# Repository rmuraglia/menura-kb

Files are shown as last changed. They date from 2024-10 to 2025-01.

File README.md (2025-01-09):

# menura

menura-build-collage

The menura is a 30 to 36 key wireless split MX keyboard compatible with the [VIK standard](https://github.com/sadekbaroudi/vik) for modular peripheral device support.

The core concept is a single PCB design which supports *mimicry* of many physical layouts, allowing for non-committal experimentation.
This is accomplished by utilization of overlapping (but not mutually exclusive) switch footprints, and a PCB shape which permits effective conversion to the unibody form factor.

The menura is named for the [lyrebird](https://en.wikipedia.org/wiki/Lyrebird) (scientific name, *menura*), due to its skill in mimicry:

> They are most notable for their impressive ability to mimic natural and artificial sounds from their environment  
> [...]  
> It is one of the world's largest songbirds, and is renowned for its elaborate tail and courtship displays, and its excellent mimicry.

# Design goals

The primary design goal was to create a PCB that would allow you to seamlessly switch between and try out many layouts, gradually reducing your keycount from a 3x5+3 layout like on the [5 column ffkb](https://fingerpunch.xyz/product-tag/ffkb/), to 3x5+2 like the [sweep](https://github.com/davidphilipbarr/Sweep), then eventually a 23332+2 like the [hummingbird](https://github.com/PJE66/hummingbird).  
In parallel to the keycount flexibility, I also wanted it to be easy to try out both a true split layout as well as unibody layouts ranging from the aggressively angled like the [barobord](https://github.com/sadekbaroudi/barobord) to more relaxed angles like the [duet](https://github.com/zzeneg/duet).

To accomplish this goal, the menura has two key features:

## Partially overlapping switch footprints

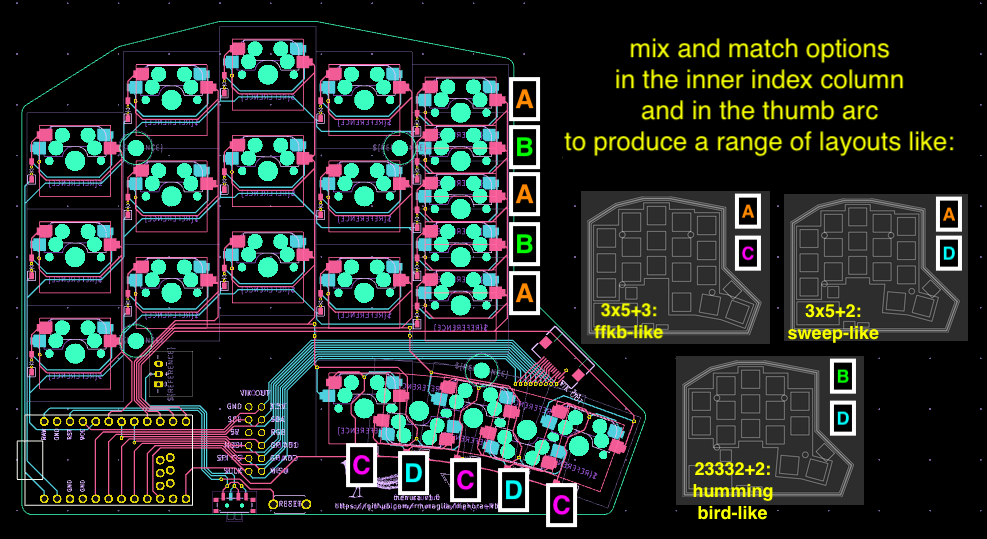
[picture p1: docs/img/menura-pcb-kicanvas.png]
menura-pcb-kicanvas


By carefully arranging switch footprints, we can set it up such that *all* hotswap sockets can be soldered without interfering with each other.  
This allows you to defer the choice of layout to case assembly time rather than being forced to commit irreversibly at PCB build time, encouraging experimentation.

This requires a concession to use MX switches only.
Reduced choc spacing and the shape of choc hotswap sockets make simultaneous installation of all switch sockets impossible (at least without compromising on switch rotation, which impacts keycap compatibility, etc).

## MCU relocation and unibody wedges

To allow for effective and flexible unibody conversion, the MCUs needed to be relocated out of their conventional spot next to the inner index column.
Without this modification, we cannot get the halves close enough together to accurately mimic unibody layouts.

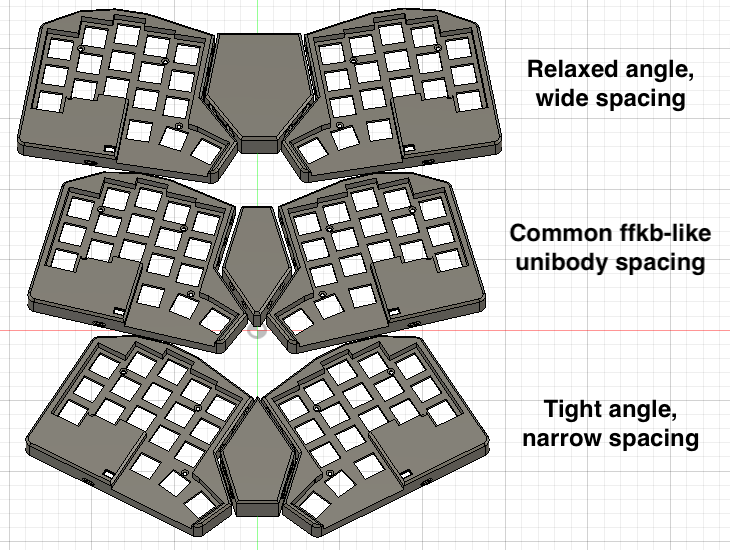
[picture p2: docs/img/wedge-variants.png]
wedge-variants


The resulting PCB edge cut enables a case + wedge design that can reproduce a wide range of unibody angles and inter-half distances.  
The case designs in this repo support insertion of magnets into the case walls to allow for simple insertion and removal of the wedges.

## VIK support

Finally, after accomplishing the two previous goals, to lean into the theme of flexibility, versatility and experimentation, we added support for the [VIK standard](https://github.com/sadekbaroudi/vik) for peripheral device support.
This means that with one flat flexible cable (FFC), you can integrate a wide range of add ons, like a nice!view display or a cirque trackpad.

# Building your own menura

To build your own menura:

1. Order PCBs from somewhere like [JLC](https://jlcpcb.com/) using the gerbers in the [releases](https://github.com/rmuraglia/menura-kb/releases) section of this repo
2. Follow the [build guide](/docs/build-guide.md) to:
    1. Solder the PCB
    2. Assemble the case, using a case printed from the [`case/`](/case/) directory
3. Flash the [ZMK studio](https://zmk.dev/docs/features/studio) ready firmware from the [releases](https://github.com/rmuraglia/menura-kb/releases) section of this repo for testing and basic keymap customization
4. If needed (for advanced keymap configuration), write and flash your own ZMK firmware, using the [menura shield module](https://github.com/rmuraglia/zmk-keyboards-menura). The ZMK docs has a page on [modules](https://zmk.dev/docs/features/modules), for more details on using modules

If you want to quickly inspect the PCB or schematic to debug something or further understand the design, you can quickly view these in browser with kicanvas: [menura in kicanvas](https://kicanvas.org/?github=https://github.com/rmuraglia/menura-kb/blob/main/pcb/menura.kicad_pro).  
Tip: in the pcb view, within the sidebar's objects section (with the triangle, circle and square icon), you can turn the slider for "zones" all the way down to stop displaying the ground fill to better see the traces and footprints. 

# Inspiration and references

The board's concept, with flexible key positions and the ability to use two split halves as one whole was inspired heavily by [ErgoTravelXT](https://github.com/FIXMBR/ErgoTravelXT).  
The layouts the menura attempts to mimic include the [ffkb](https://fingerpunch.xyz/product-tag/ffkb/), the [vulpes minora](https://github.com/sadekbaroudi/vulpes-minora), the [sweep](https://github.com/davidphilipbarr/Sweep) and [urchin](https://github.com/duckyb/urchin), the [hummingbird](https://github.com/PJE66/hummingbird), and countless others.

On the design side, I learned a ton on the ergogen side from the [nostrum](https://github.com/bennytrouser/nostrum), [trochilidae](https://github.com/jcmkk3/trochilidae) (rufous and berylline), and [corax](https://github.com/dnlbauer/corax-keyboard) configs, as well as [flatfootfox's guide](https://flatfootfox.com/ergogen-introduction/).  
Other boards I studied on the kicad side include the vulpes minora, urchin, [temper](https://github.com/raeedcho/temper) and [klotz](https://github.com/GEIGEIGEIST/KLOTZ).
zzeneg's [zzkeeb](https://github.com/zzeneg/zzkeeb) library was critical in helping me cut through the endless options for kicad footprints to find an organized and curated set to start with.

# Thanks

I'd like to thank Sadek Baroudi and the members of the [fingerpunch discord](https://discord.gg/ewS6xbCgPb) community, especially Hazel who (unwillingly) taught me everything I know, Saixos and bravekarma for teaching me how to do things right (even if I usually ignored their suggestions), and reeve, damselfly, Yingeling and PyntieHet for celebrating every small step along the way and encouraging me to finish the project.

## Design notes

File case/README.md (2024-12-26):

I've tried to make design files available in a wide variety of formats to support editing and redesign as needed:

1. `fusion/` contains fusion 360 files for complete control over the timeline and features for editing
2. `step/` contains step files for non-meshified exports which better preserve the underlying geometry for minor tweaks and portability outside of fusion
3. `stl/` contains exported meshes, which are not great for editing, but are convenient for printing
4. `dxf/` contains outlines which you can use to start a new case design from scratch. See [the case design docs](/docs/case-design.md#shadow-line) for some notes on the generated outlines (and why you may want to export something different from ergogen, depending on your use case)

The exported case files are generally going to follow one of the three naming schemes:

- `bottom`: this is the simplest case -- there's just one common bottom for all cases, so there's no variants to track. Fusion and step files will have one common file for both halves, whereas stl will export a left and right separately.
- `top_${layout}`: where layout is be one of `3x5_3`, `3x5_2`, `23332_2` etc. For stls, there's again left and right exports, as well as exports for variants with `no-rst`, no cutout for the reset button
- `wedge_${angle}_${distance}_${feature}`: the angle refers to the angle between a keyboard half and the vertical, and the distance refers to the distance between the top corners of the keyboard halves. The (optional) feature represents any peripheral you may mount in the wedge, like a cirque trackpad.

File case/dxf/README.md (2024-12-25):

- the `raw` directory contains dxf exports from ergogen as is
- the `cleaned` directory contains dxf exports from fusion after I've done some minor clean up and modification (closing gaps in outlines, trimming internal lines, extending lines to section off areas that I want to treat as different faces)
- the `components` directory contains dxfs for components (e.g. cirque trackpad) or other reusable portions (e.g. magnet cutouts) from the designs
    - the `cirque` dxf is derived from the [bad wings v1 step case file](https://github.com/hazels-garage/bad-wings/tree/master/v1/cases/original)
    - the magnets are named as `magnet-${diameter}-${edge}`, where the edge is either the shorter or longer edge of the case where the magnets will be embedded

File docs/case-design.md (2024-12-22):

This is more of a personal archival note to document how I did this case design, and isn't really intended for external consumption, but you're welcome to browse it.

# General case shape

Overall, my starting point for building understanding on fusion 360 and case design were:

- [Sadek Baroudi's case design guide](https://github.com/sadekbaroudi/keyboard-guides/tree/master/cases)
- [Hazel's bad wings v1 original case](https://github.com/hazels-garage/bad-wings/tree/master/v1/cases/original), and the minor tinkering I did in that case
- The (unpublished, but shared privately) fusion design file for the [vulpes minora case](https://github.com/sadekbaroudi/vulpes-minora/tree/master/case).

My general approach was going to follow the same general case design composed of:

- a flat bottom plate
- a top switch plate, with offset walls to "reach down" to the plate, and hollowed out areas to provide clearance for top-of-pcb components like the MCU

## Measurements

Base measurements:

- PCB and plate thickness: 1.6mm
- hotswap socket thickness: 1.8mm
- switch bottom to housing to top of clip point: 5mm (from [cherry switch diagram](https://www.cherry.de/en-gb/gaming/developer))
- PCB bottom to USB top: 10mm (on left side, where USB is taller -- this is the tallest component which will determine the overall height)

cherry-switch-dimensions

In general, this integrated plate design suggests that using the bottom of the switch plate as the vertical "origin" from which we will determine relative measurements makes sense.

Derived measurements:

- switch plate top to usb top: 3.4 (10 - 1.6 - 5)
- switch plate bottom to usb top: 5 (3.4 + 1.6)
- mcu hollowed out area: 5.4 (5 + 0.4 buffer) to 7 (+1.6 wall thickness)
    - important: +7 is the max height
    - note that the 0.4 buffer sounds small, but really the height of the usb port (with magnetic tip) is much more than the mcu board itself, so this should be plenty
- switch plate top to bottom of sockets: 6.8 (5 - 1.6 (housing minus plate thickness) + 1.6 (pcb) + 1.8 (sockets))
    - note: Sadek's case guide suggests 8 mm as a safe height for MX hotswap

## Shadow line

This [hackaday article](https://hackaday.com/2023/08/07/enhance-your-enclosures-with-a-shadow-line/) gives a good overview of shadow lines, but the concept is that you use mating pieces, such that on the inside, the parts are flush, but on the outside there is a small gap -- this gap, backed by the flush pieces gives a better appearance of uniformity at the seam, compared to just attempting to get the outermost walls flush with each other.

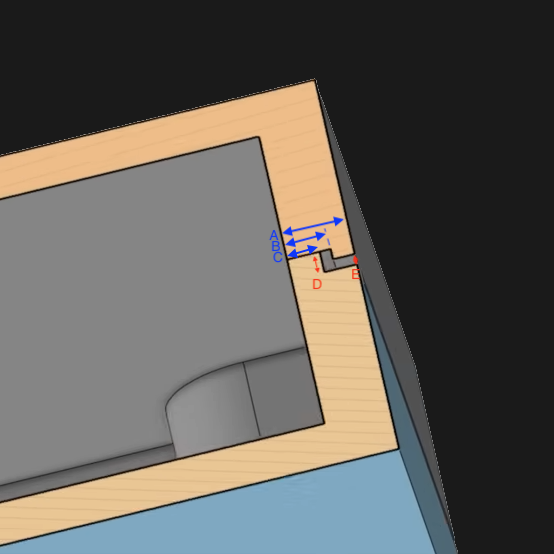
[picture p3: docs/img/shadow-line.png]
shadow-line


I rotated and annotated it, to suit my desire to have the top create the gap with an overhang, rather than the bottom reaching up.  
For ease of FDM printing, I was advised to choose measurements in multiples of the nozzle and layer height, so 0.4mm was selected. Some discussion in discord on the topic: [link](https://discord.com/channels/989552667330228374/1104037399517986947/1306638628612739103).

The measurements I ended up choosing were as follows:

- total wall thickness (A): 3mm
- inner wall thickness (C): 1.2mm
- horizontal gap: 0.6 (3 - 1.2 - 1.2 for even wall thicknesses)
    - implies B (outer wall offset) is 1.8 (1.2 + 0.6)
- vertical gap (E): 0.4
- vertical mating notch (D): 1.2 (0.4 gap + 0.8 step)

To minimize repeated manual work in fusion (offsetting curves in sketches), I added outlines for these additional wall thicknesses to my ergogen config (see `(board|shadow)_(inner|outer)_wall`).  
These outlines are all generated with no fillet, to help fusion import gapless DXFs that require minimal fixing.  
Note that this lack of filleting in the ergogen stage will come back to bite us in the [cosmetics](#cosmetics) section, so be sure to check that out.

# Fusion

With all of those measurements in place, we can do the basic extrudes in fusion that give the case its general shape:

## Sketch modifications

Before extruding, I did do some minor sketch modifications to make the extruding easier:

1. I sectioned off the hollow areas, so it can be treated as a different face for extrusion. This generally means extending some lines:
    1. bottom pinky bottom edge to the left wall
    2. tucky thumb tucky edge to bottom wall
    3. reachy thumb reachy edge to bottom wall
    4. vik top and bottom edges to right wall
2. I also cleaned up some leftover, internal lines that did not meaningfully contribute to the outline:
    1. bottom of power switch
    2. bottom left mounting hole
    3. vik and jst overlap
3. Last to provide a wall to connect the raised, hollow areas with switchplate-height part of the case, I added some offsets around the mcu and vik connector.

## Extrudes

1. Bottom going up:
    1. main pcb area: 1.6 baseline thickness
    2. inner ring: 1.6 base + 0.4 gap + 0.8 step = 2.8
    3. middle and outer ring: 1.6 baseline thickness
2. Top going down (from switch plate bottom):
    1. inner + middle wall: 6.8 (meet the 1.2 extra height of the inner ring from the bottom to make a flush 8mm height)
    2. outer ring: 7.6 (6.8 + 0.8 step, leave a 0.4mm shadow line gap)
3. Top going up (from switch plate bottom):
    1. switch plate and thumb cutout: 1.6 baseline thickness
    2. solid max height area (e.g. connecting walls to hollow areas, areas between switches and outer edge of case): 7mm (previously determined max height)
    2. mcu hollowed out area: 5.4 - 7

At this point, I also add the m2 countersunk holes at all the mounting points. 
Note that the outer diameter of the countersunk screw head clearance is 4.4mm.

## Component cutouts

Next we need to add cutouts or windows for all the components.
Luckily, the ergogen config already has these rendered in the sketch, so all we have to do is *project* a relevant line from that sketch onto the desired plane, then draw around that as a reference.

### USB port

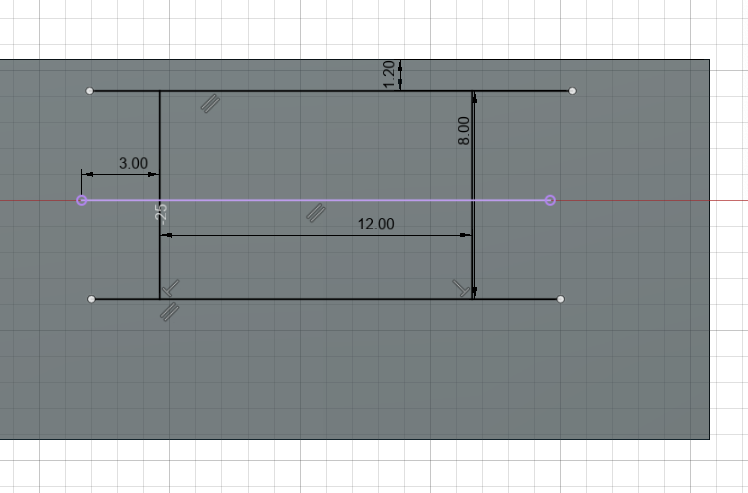
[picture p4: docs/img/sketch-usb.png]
sketch-usb


1. Project a line from the MCU outline to know where the cutout should be centered
2. We know that the top of the USB port *should* be 1.6 to 2 mm from the top of the case (based on the case thickness + 0.4 buffer we allowed)
3. So we start the cutout at **1.2mm from the top** of the case to give a bit more breathing room
4. Then we know we want the cutout to be **8mm tall**, just from other designs -- this gives room for the chunky magnetic tip, and gives some vertical allowance for the flipped MCU on the right/left sides which influences the USB port mounting
5. Then we see the projected line is *18mm* long, and we want our cutout to be centered along that. We want the cutout to be **12mm wide** (again from other designs), so we start the cutout **3mm offset from the end** of the projected line

### Power switch

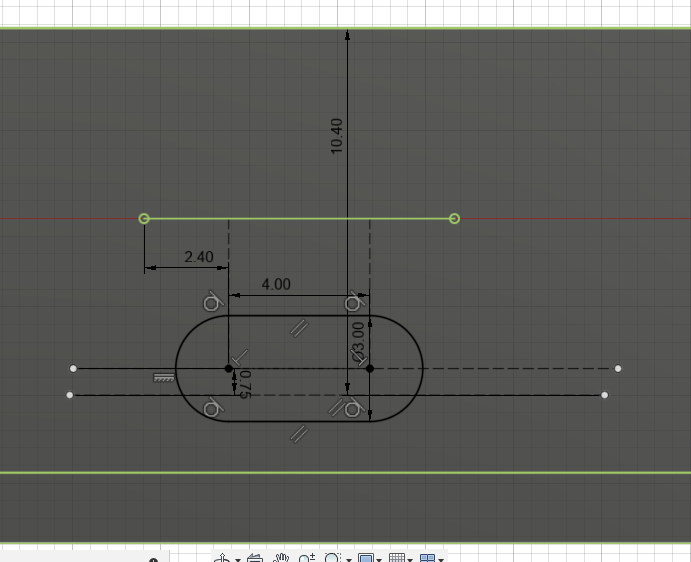
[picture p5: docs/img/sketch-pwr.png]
sketch-pwr


1. The power switch sits on top of the PCB, so we first make a reference line 10.4mm from the top of the case for the top of the PCB: 7 from top of case to switchplate bottom + 5 for switchplate top to pcb top - 1.6 for switchplate thickness
2. The projected line is 8.8mm wide, and we want our power switch cutout slot to be constructed as a center-to-center slot, with a 4mm wide distance between centers, so we measure a horizontal offset of 2.4mm
3. The slot is vertically centered 0.75mm above the top of the PCB (I honestly don't remember why, this is probably the half the thickness of the power switch)
4. Finally, we create the slot based on those centers, with a slot height of 3mm, giving us two 1.5mm radius semi circles on the ends.

For the power switch, we additionally create a second cutout in the wall to create a channel for the protruding switch to go through during PCB insertion to the case.  
In this case, the actual toggle switch is small, so we just arbitrarily cutout the width of the rectangular portion of the slot up to the midpoint of the wall thickness.
For chunkier toggles, you may want to be more precise here.

### Reset button

1. For this, we are actually making a cutout in the plane of the component's sketch, so it is really simple
2. The only change is that instead of using the full footprint's width (9mm), we just make the cutout 6mm wide, which is the width of the button itself, so we offset horizontally by 1.5mm on one side.

### Vik cable

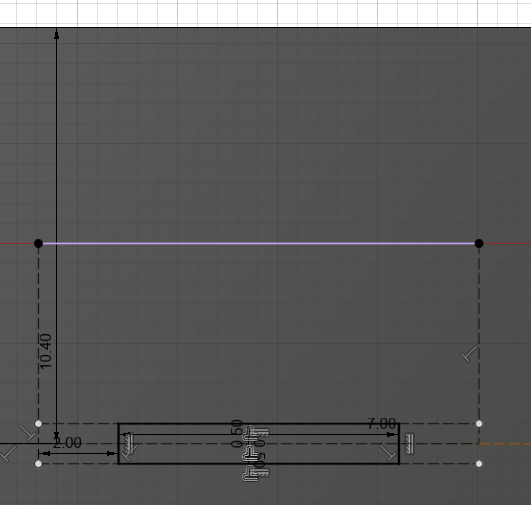
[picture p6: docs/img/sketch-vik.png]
sketch-vik


1. The vik cable will be roughly aligned with the top of the PCB, so the cutout will be centered **10.4mm from the top** of the case. (7 from top of case to switchplate bottom + 5 for switchplate top to pcb top - 1.6 for switchplate thickness)
2. The FFC cable slit will be **7mm wide and 1mm tall**
3. The reference projected line from the footprint is 11mm long, so we offset by 2mm on the side

## Magnet holes

For the magnet holes, I received a few tips, based on [this model](https://github.com/VoronDesign/Voron-Tap/blob/29e900094a0f094aad88493c76ec5a6d39f94812/STLs/Tap_Center_left_r8.stl) and this discord [conversation](https://discord.com/channels/939959680611020840/1054306614158557214/1308157606388437072):

1. For circular magnets, instead of attempting to fit it exactly to a circular hole, use a slightly undersized circumscribed hexagonal hole instead. This will give you a good combination of flex and relief, giving you the best fit possible with some printing tolerance
    - For 8mm magnets, I found a 7.95mm diameter hole to work well (any bigger was too loose)
    - For 5mm magnets, I found a 4.95 diameter hole to have mixed success.
        - In the wedge piece, it worked great, but in the case piece it was too tight. This may be due to different body rigidities and different amounts of Z-axis squishing during printing.
2. Add a small undercut at the bottom of the hole to deal with printing artifacts in inside corners.
    - note that in practice, I did not find this tip to be necessary for my magnets (probably because they are thinner than the advertised thickness, so they didn't need to be seated totally flush in the hole)

Separately, [this video](https://youtu.be/Bd7Yyn61XWQ) had some good tips on printing holes, the main one that I used was adding a chamfer to the hole to help guide a part for insertion.
I used a **0.4mm chamfer**, which seemed to work well.

And lastly, in addition to relief via the hex shape, I added a 1.5mm tall slot running across the magnets to serve as both extra relief, and also as a channel where I could insert tweezers to pry out misplaced magnets (e.g. in the wrong orientation).

Specific to my case, I chose [8x2mm magnets](https://www.amazon.com/gp/product/B09BB1VT4J/), as I thought those would conveniently embed into my 3mm thick case wall.  
I wanted to ensure that the magnet was mostly embedded in a portion of the wall that was 3mm thick, and not a portion that was thinner due to the shadow line overhangs.  
This meant that I set the magnet midpoint to be **6.9mm from the top of the case**, from (7 (upwards extrude) + 6.8 (inner + middle wall downwards extrude))/2.

Finally, again, specific to my case, I spaced the magnets out as shown below (unscientifically):
For the longer edge, I put one magnet in the center, then offset centers by 13mm for even spacing:

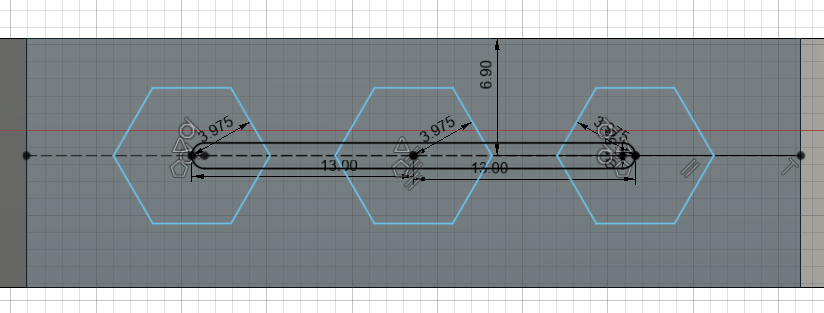
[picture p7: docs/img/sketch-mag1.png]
sketch-mag1


For the shorter edge, the magnets are a set a bit more arbitrarily to work around the vik slot:

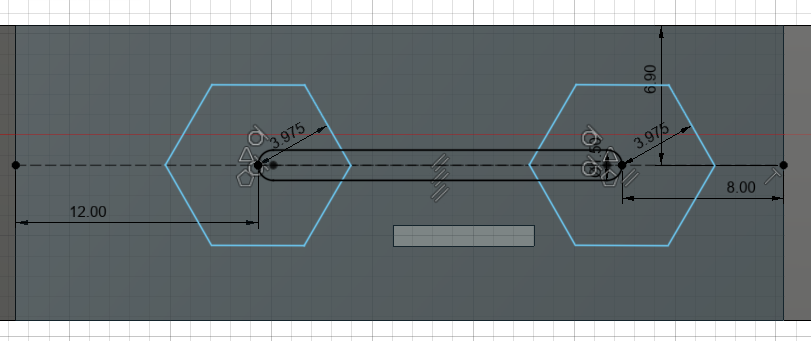
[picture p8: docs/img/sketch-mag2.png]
sketch-mag2


## Cosmetics

### Fillets

Recall that the outline of the PCB is filleted with a value of 5 in ergogen, but the exported outlines for the case are not.
You will want to recreate this fillet.  
For outer corners, and corners part of the outer shadow line wall, use the same 5mm value.  
For corners part of the inner shadow line wall (where the PCB would actually contact the case), use a smaller 2mm value.

In theory, I feel like 5mm should be fine for all of these, but in practice, 5mm on the inner walls added too much material and made the PCB rub against the case.

### Chamfers

I used chamfers to just make the edges of the case less severe.
Some values for reference (unscientifically chosen):

- 1.5mm along the top edge of the case
- 0.4mm around the reset button cutout
- 0.5mm around the power switch cutout
- 1mm around the usb port cutout

# Center wedge

To create the center wedge, there are two main levers that are captured in the file name:

1. the angle between a piece and the vertical
2. the distance between the top of halves

This seems like it would be well suited to [parametric modeling](https://help.autodesk.com/view/fusion360/ENU/?guid=GUID-76272551-3275-46C4-AE4D-10D58B408C20) but in practice, I wouldn't get this to scale/regenerate assets well.

In general my procedure was:

1. Import a basic sketch of the case outline (e.g. the bottom plate should be sufficient, as long as it accounts for the added wall thickness)
2. Rotate the outline by the desired split angle (e.g. for ffkb or bad wings, this is 15 degrees from the vertical, so the halves are 30 degrees from each other)
3. Draw a vertical line that's horizontally offset to half of the desired spacing (use a sketch dimension)
4. Move/copy the outline as a rotation about that line to create a mirrored copy of the outline
5. Connect lines across the mirrored copy and original to create a closed face in the middle.
6. If necessary, draw features in that center face (e.g. display or trackpad slot)
7. Extrude the face to a total height of 16.6mm (1.6 bottom plate thickness + 8mm to switch plate bottom + 7 switch plate bottom to top)
8. Create magnet cutouts to match those in the case (magnet center is 6.9mm from top)
9. If necessary, create vik slot aligned to that from the case, hollow out body to make room for accessory PCB and components
10. Chamfer the top edge to match the case (1.5mm)

Note to future self: the first wedge I made (15 deg, 18mm) was actually defined by a 4mm distance on the bottom of the wedge, so the 18mm is not quite right (it is more like 18.5).

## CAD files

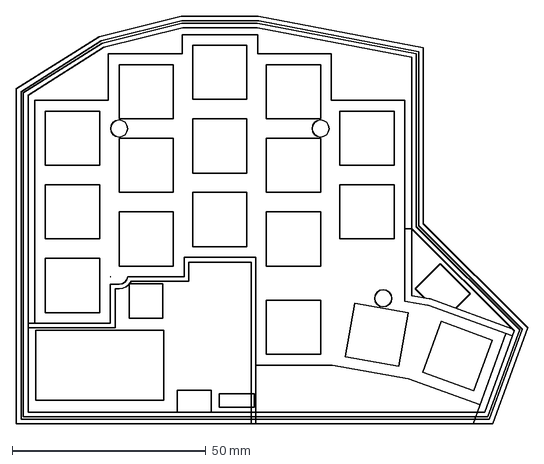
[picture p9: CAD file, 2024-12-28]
case/dxf/cleaned/case_plate_33332_3.dxf
131.9 x 105.2 mm

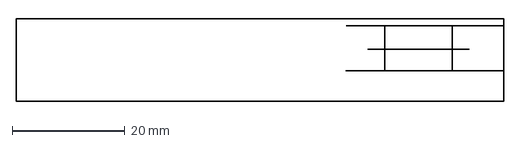
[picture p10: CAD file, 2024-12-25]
case/dxf/components/cutout-usb.dxf
86.4 x 14.6 mm

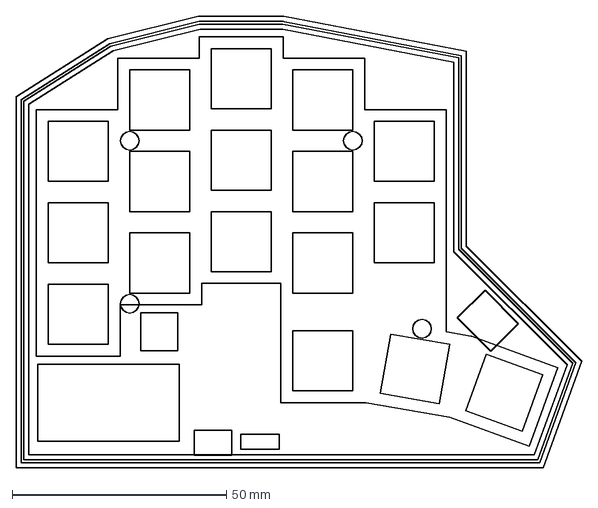
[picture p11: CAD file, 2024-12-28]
case/dxf/raw/case_plate_33332_3.dxf
131.9 x 105.2 mm

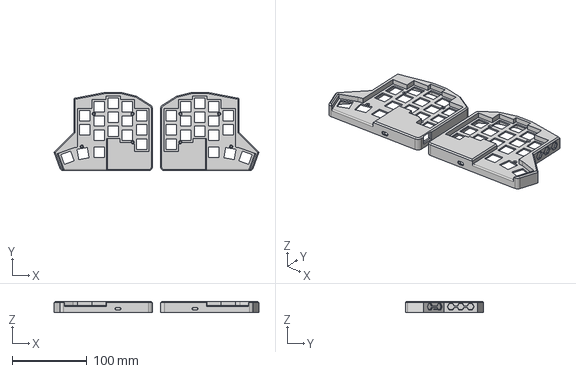
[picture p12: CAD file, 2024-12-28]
case/step/top_33332_3.step
274.8 x 105.2 x 14.6 mm

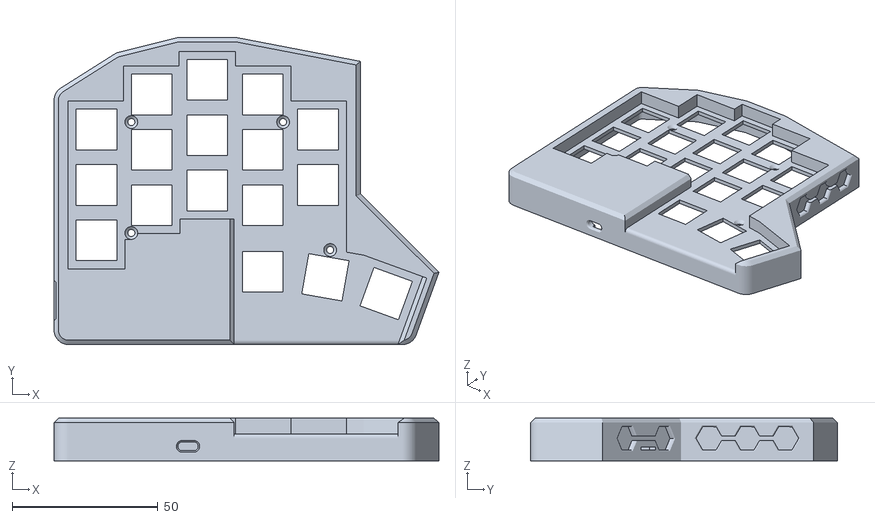
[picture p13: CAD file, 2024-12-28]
case/stl/top_33332_3_left_no-rst.stl
131.9 x 105.2 x 14.6

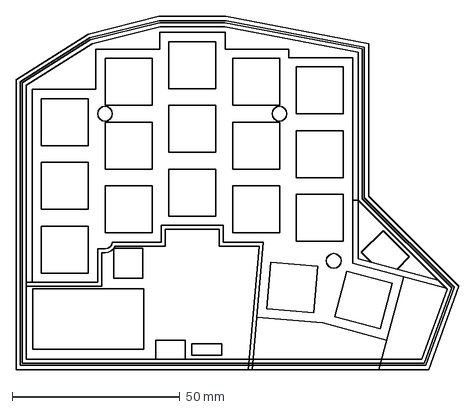
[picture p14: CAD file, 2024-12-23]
case/dxf/cleaned/case_plate_3x5_2.dxf
131.9 x 105.2 mm

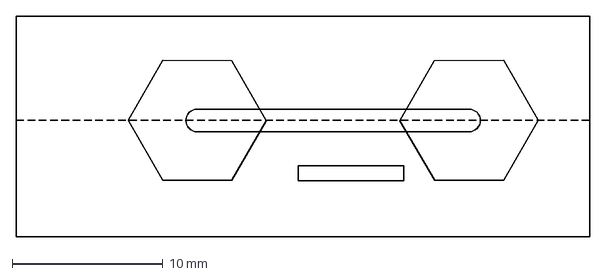
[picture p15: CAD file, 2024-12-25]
case/dxf/components/magnet-8mm-short.dxf
38.0 x 14.6 mm

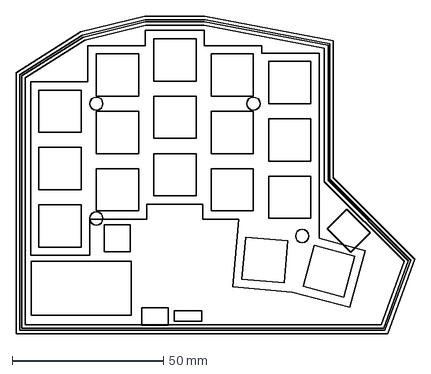
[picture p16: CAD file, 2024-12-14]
case/dxf/raw/case_plate_3x5_2.dxf
131.9 x 105.2 mm

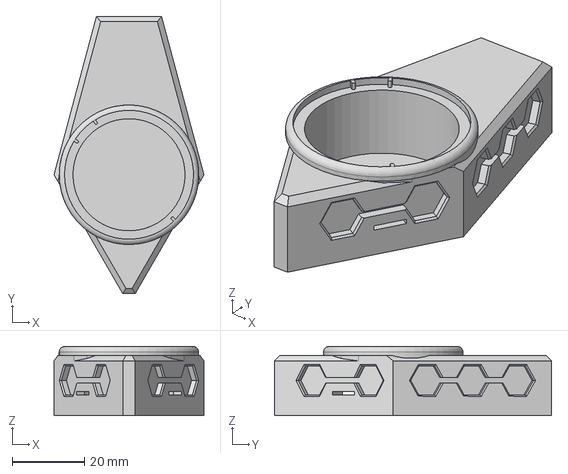
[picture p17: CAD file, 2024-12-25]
case/step/wedge_15deg_18mm_cirque.step
41.5 x 76.8 x 19.1 mm

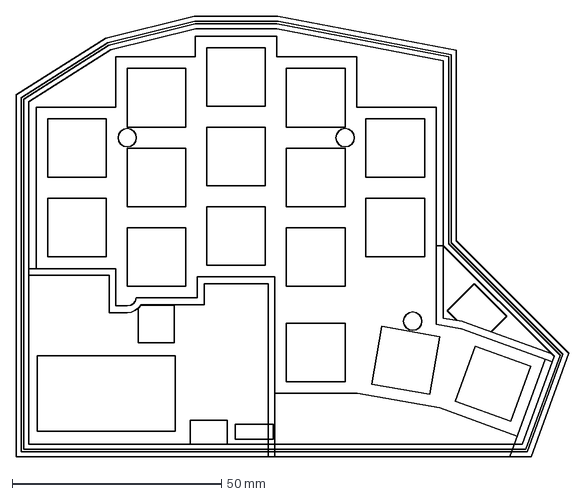
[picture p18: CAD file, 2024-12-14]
case/dxf/cleaned/case_plate_23332_3.dxf
131.9 x 105.2 mm

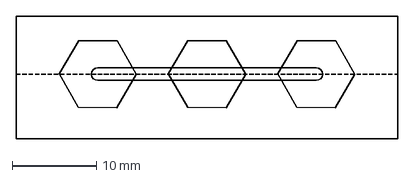
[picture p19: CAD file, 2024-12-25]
case/dxf/components/magnet-8mm-long.dxf
45.4 x 14.6 mm

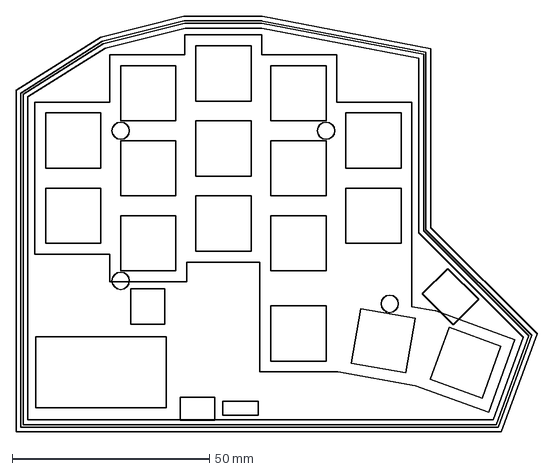
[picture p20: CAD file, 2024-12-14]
case/dxf/raw/case_plate_23332_3.dxf
131.9 x 105.2 mm

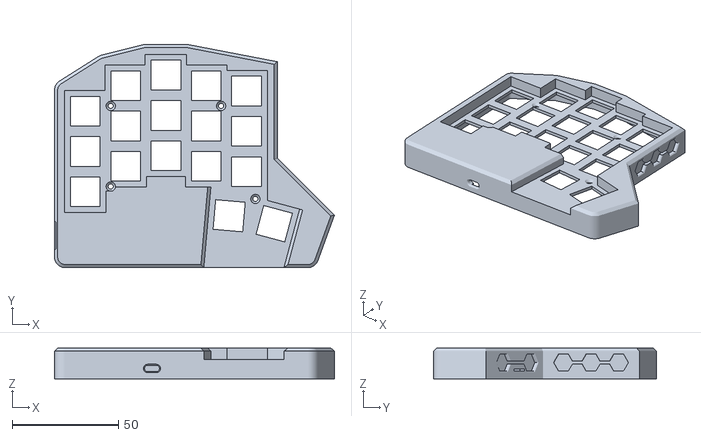
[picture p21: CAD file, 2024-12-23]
case/stl/top_3x5_2_left_no-rst.stl
131.9 x 105.2 x 14.6

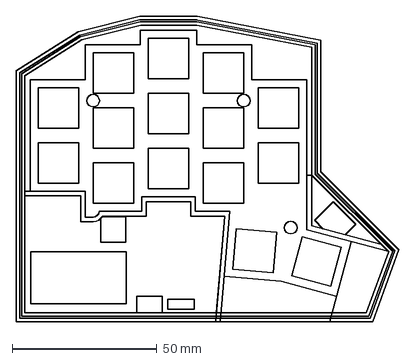
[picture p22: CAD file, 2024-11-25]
case/dxf/cleaned/case_plate_23332_2.dxf
131.9 x 105.2 mm

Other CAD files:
case/stl/top_33332_3_right_no-rst.stl
case/step/top_3x5_2.step
case/dxf/components/cutout-pwr.dxf
case/dxf/raw/case_bottom.dxf
case/dxf/cleaned/case_bottom.dxf
case/dxf/cleaned/case_plate_3x5_3.dxf
case/dxf/components/cirque.dxf
case/dxf/raw/case_plate_23332_2.dxf
case/dxf/raw/case_plate_3x5_3.dxf
case/fusion/bottom.f3d
case/fusion/top_23332_2.f3d
case/fusion/top_23332_3.f3d
case/fusion/top_33332_3.f3d
case/fusion/top_3x5_2.f3d
case/fusion/top_3x5_3.f3d
case/fusion/wedge_10deg_34mm.f3d
case/fusion/wedge_10deg_50mm.f3d
case/fusion/wedge_15deg_18mm.f3d
case/fusion/wedge_15deg_18mm_cirque.f3d
case/fusion/wedge_30deg_0mm.f3d
case/step/bottom.step
case/step/top_23332_2.step
case/step/top_23332_3.step
case/step/top_3x5_3.step
case/step/wedge_10deg_34mm.step
case/step/wedge_10deg_50mm.step
case/step/wedge_15deg_18mm.step
case/step/wedge_30deg_0mm.step
case/stl/bottom_left.stl
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

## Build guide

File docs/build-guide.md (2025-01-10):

# Building the PCB

## BOM

| Part | Quantity | Notes |
| --- | --- | --- |
| menura PCB | 2 | PCB is reversible. Fabrication files can be found in the [releases](https://github.com/rmuraglia/menura-kb/releases) section. |
| controller | 2 | [nice!nano](https://nicekeyboards.com/nice-nano) or [suitable alternative](https://github.com/joric/nrfmicro/wiki/Alternatives#supermini-nrf52840) |
| (optional) controller sockets and pins | 48 | e.g. [sockets](https://github.com/joric/nrfmicro/wiki/Sockets) |
| diode | 44 | SOD-123 1N4148W [example](https://www.lcsc.com/product-detail/Switching-Diode_GOODWORK-1N4148W_C909967.html) |
| hotswap socket | 44 | MX |
| reset button | 2 | through hole 2 pin 3x6mm, e.g. [MJTP1243](https://www.digikey.com/en/products/detail/apem-inc/MJTP1243/1798039) |
| power switch | 2 | PCM12-like, e.g. [MSK12C02](https://www.lcsc.com/product-detail/Toggle-Switches_SHOU-HAN-MSK12C02_C431540.html) |
| (optional) battery jack | 2 | 2-pin JST PH e.g. [S2B-PH-K-S](https://www.digikey.com/en/products/detail/jst-sales-america-inc./S2B-PH-K-S/926626) |
| battery | 2 | [301230 lipo](https://github.com/joric/nrfmicro/wiki/Batteries#301230) recommended for ease of tucking under mcu |
| (optional) FFC connector | 2 | 12 pin, 0.5mm pitch [example](https://www.lcsc.com/product-detail/FFC-FPC-Connectors_SHENZHEN-ATOM-TECH-FPC05012-09200_C479750.html) |

## Build order

This is the order (and location) in which I like to install the components:

1. **Diodes**: install these on the *bottom* of the PCB. The line on the diode should be closer to the pad enclosed by a silkscreen marking. If this is unclear, please check the [build tips](#build-tips) section below.
2. **Hotswap sockets**: install on the *bottom* of the PCB
3. **Power switch**: install on the *top* of the PCB. You may install it on the bottom if you prefer, but you will then have to adjust the case
4. **Controller**: install on the *top* of the PCB. It is strongly recommended to socket your controller with sufficiently tall sockets so you can put the battery between the controller and the PCB. Be sure to align the labeled pins -- this means that on the left, the MCU will have the components on top, and on the right, the components will be facing down. If you are not confident in determining the controller orientation, I suggest reviewing the [build tips](#build-tips).
    1. ⚠️ WARNING⚠️  If you are intending on putting the battery under the socketed controller, do *not* solder the three internal pins on the controller. If you do, you will not be able to slide the battery under the controller easily anymore.
5. **Reset button**: install on *top* of the PCB. You may install it on the bottom if you prefer, but you will then have to adjust the case
6. **Battery jack**: install on *top* of the PCB. Note that you will only use 2 of the 3 through holes at any given time. Align the positive (+, conventionally red) terminal of your battery with the *center* hole of the footprint. Check the [build tips](#build-tips) for more detailed info. You may install this on the bottom if you prefer, etc etc
7. **FFC connector**: this footprint is only available on one side, so you don't have much of a choice 😅 

Your completed menura PCBs should look something like this, with some minor caveats -- I skipped step (7), and on the left I installed some pin headers for testing vik with the through hole breakouts.

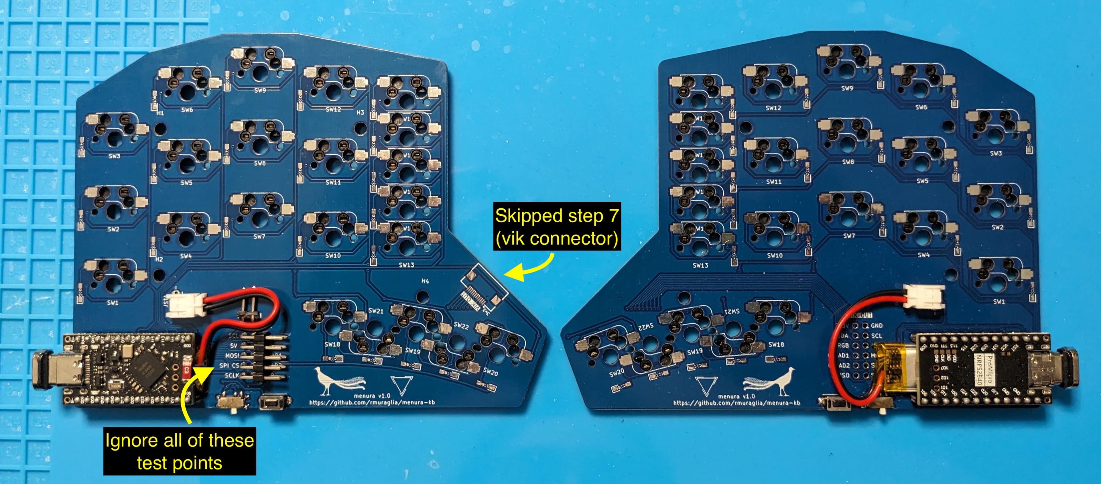
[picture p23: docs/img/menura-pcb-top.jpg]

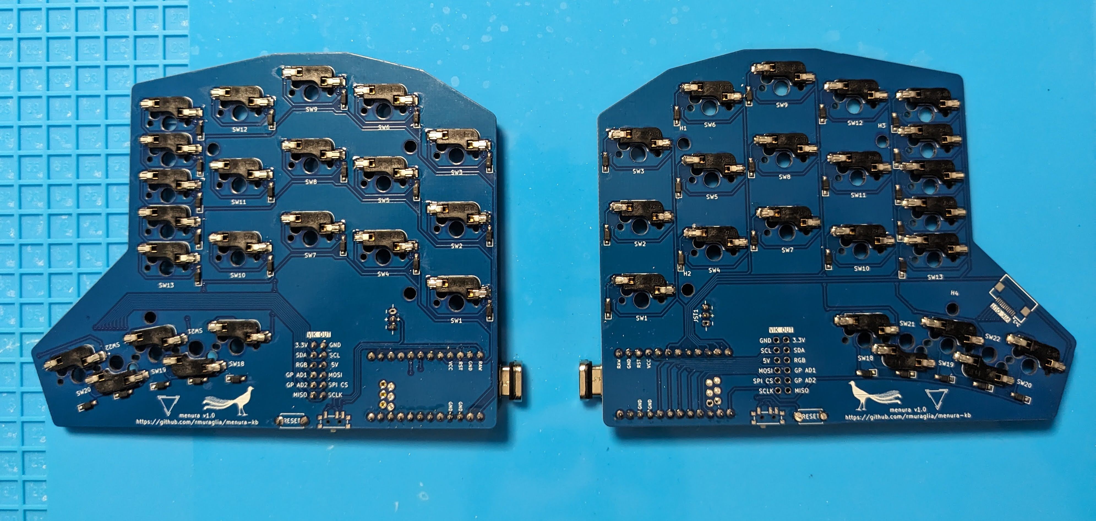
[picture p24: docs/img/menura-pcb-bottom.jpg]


> [!NOTE]
> The power switch's ON position is when it is toggled closer to the side with only one pad.
> This means that if you follow the suggestion to install the power switches on the top of the PCB, then the ON positon will correspond to toggling the switch to the LEFT.  
> Yes, this is kind of counter-intuitive and regrettable.  
> No, I did not think of this when designing it.
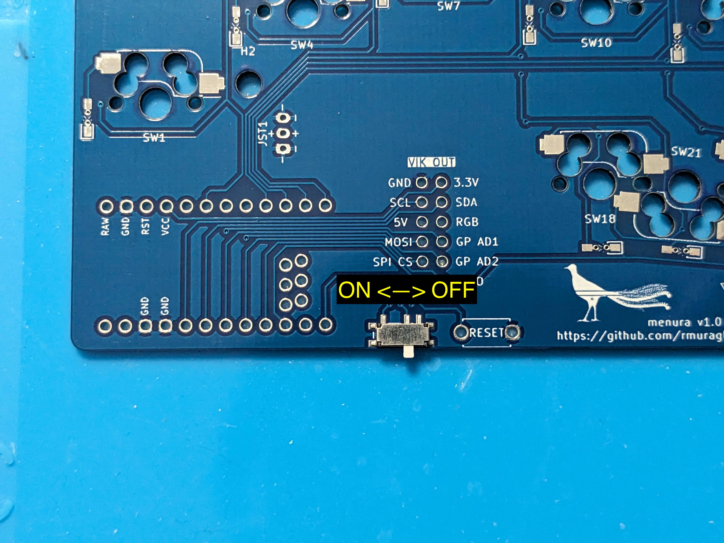
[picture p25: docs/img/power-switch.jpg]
power-switch
> 

## Build tips

If you are new to building keyboards or soldering, this section contains some tips, additional details, and visuals that should help.
If anything from that abbreviated build order is unclear, expand the section below:

<details>

<summary> Expand for general soldering tips</summary>

### Soldering SMD (surface mount) components

Via the [Kimiko build guide from keycapsss](https://keycapsss.com/help/kimiko/buildguide_en):

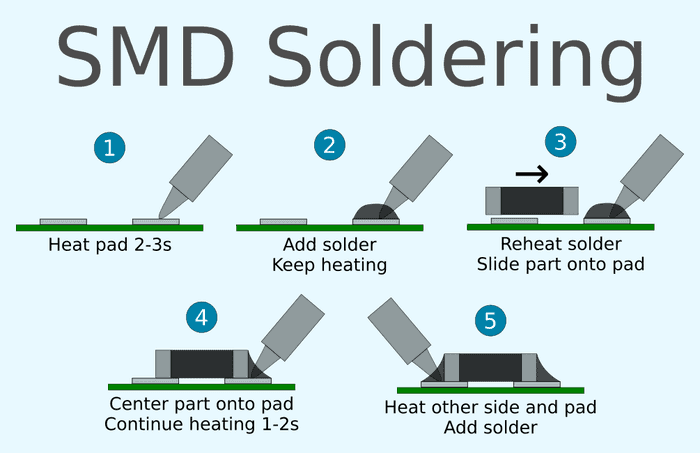
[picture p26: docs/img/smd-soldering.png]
smd-soldering


Basically:

1. tin one pad (heat and apply a little solder)
2. place the component while heating that pre-tinned side
3. once satisfied with placement and alignment, solder the other side

For self-guiding parts, like hotswap sockets which have plastic housings that fit into holes on the PCB, pre-tinning one side is not as critical -- you can just place the component and solder it in place.

### Soldering THT (through hole) components

Again, via the [Kimiko build guide from keycapsss](https://keycapsss.com/help/kimiko/buildguide_en):

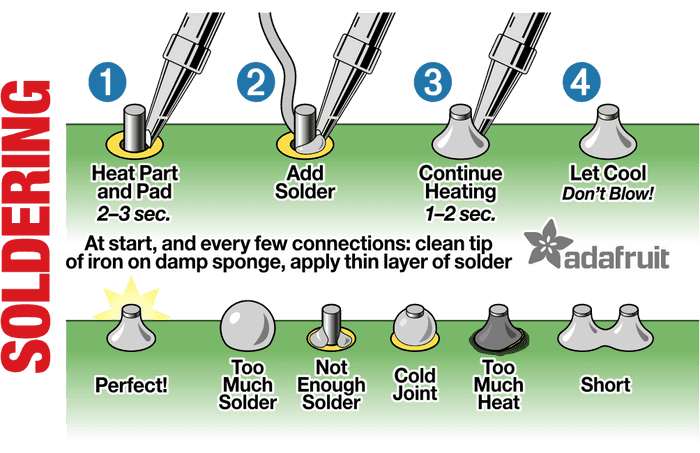
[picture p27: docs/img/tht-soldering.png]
tht-soldering


Basically:

1. place your component, and tape it in place if necessary
2. flip the board so you can access the pins poking through the plated holes
3. heat the pin **and** the hole
4. feed solder to the heated pin/hole, *not* directly to the iron -- this helps to make sure you adequately heated the part, to prevent a cold joint

### Socketing a controller

filterpaper's [guide to socketing microcontrollers](https://filterpaper.github.io/socket-mcu.html) is nice and to the point. In a nutshell:

1. Solder the sockets to the PCB
2. Cover the sockets with kapton tape
3. Insert pins by piercing through the tape
4. Solder the MCU (be **very** careful to verify the MCU orientation at this point). See the "MCU orientation" section in the next tip group if you are not sure how to determine this.
5. Remove the MCU, remove the tape, then re-place the MCU in the sockets

For step (1), a common challenge is making sure that the sockets are well aligned, vertically (i.e. pointing straight out of the hole, and not diagonally slanted).
While tape can help, it isn't always sufficient or reliable.  
I like to either use an extra set of sockets placed perpendicularly, or if you have one, an already-socketed MCU is great to force that vertical alignment:

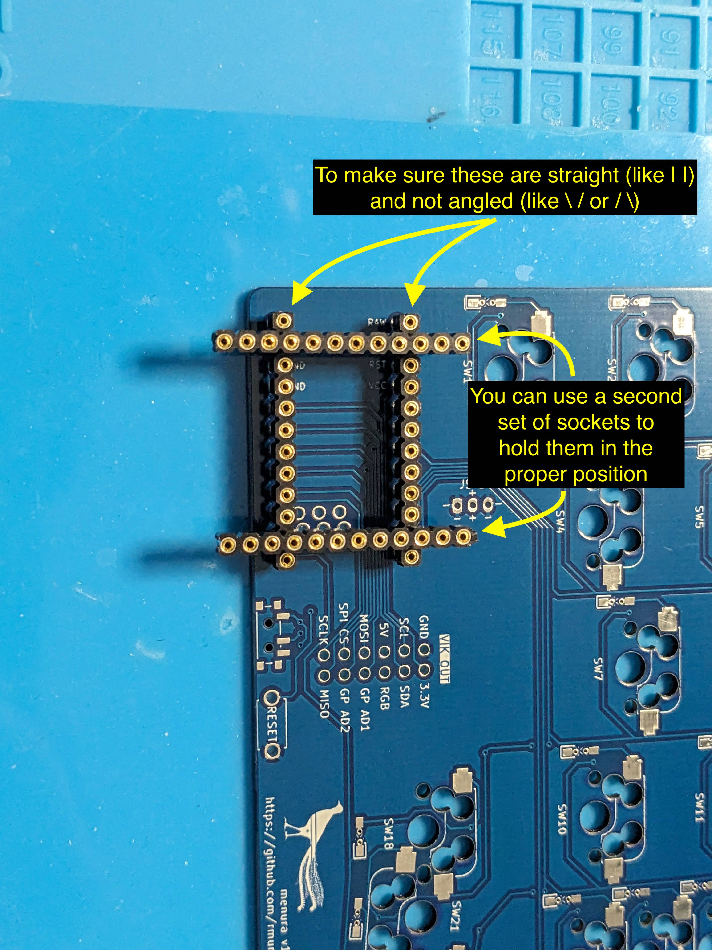
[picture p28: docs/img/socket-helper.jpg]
socket-helper


### Drag soldering fine pitch components

I've never actually done this yet! Maybe soon I will have tips based on first hand experience, but my general understanding is:

1. Apply a flux to the pins
2. Apply a blob of solder to the first pin
3. Drag the blob across the pins
4. Clean up any bridges

</details>

<details>

<summary>Expand for menura-specific build tips and info</summary>

### Parts overview

Before getting started, here is a quick visual overview of the parts you should have ready to go:

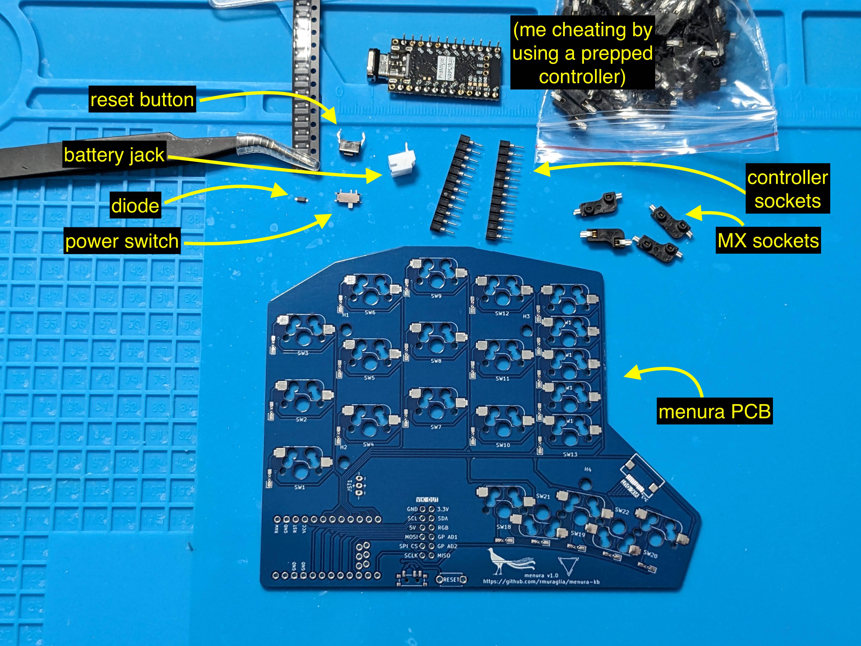
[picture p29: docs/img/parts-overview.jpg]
parts-overview


###  Diode orientation

The side of the diode with the line corresponds to the pad enclosed by a box on the silkscreen

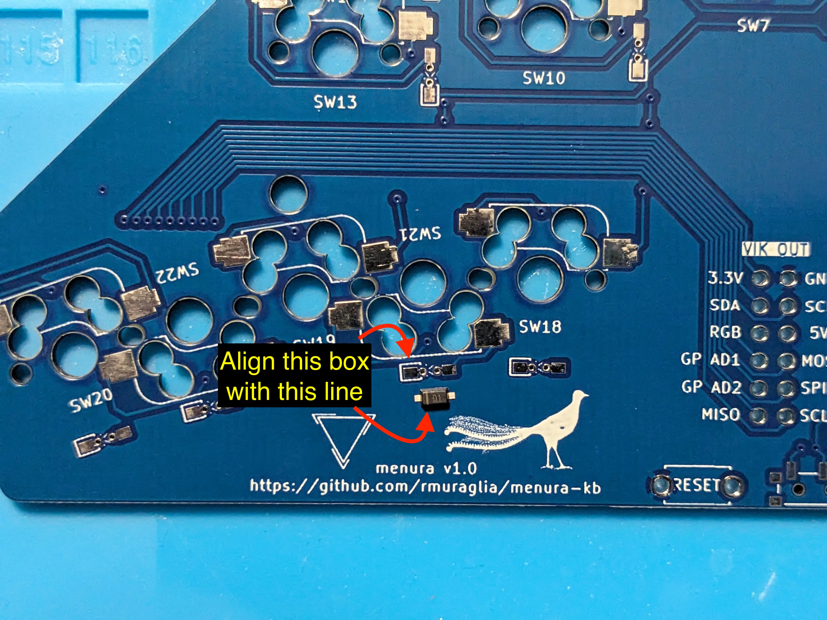
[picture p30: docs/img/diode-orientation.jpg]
diode-orientation


### Battery jack orientation

> [!WARNING]
> I assume that red on your battery corresponds to (+) based on common conventions, but this is not guaranteed.
> Before doing anything with your battery, you should [check the battery polarity with a multimeter](https://electronics.stackexchange.com/a/104377), and reverse the instructions below if necessary.

The 3-holed footprint for the 2-pin component is to provide flexiblity in battery jack orientation.
The red (+) wire of your battery will **always** go to the center hole, then you place the black (-) wire to whichever outer hole provides the most convenient orientation for you.  
For example, for my left and right sides, I orient the jack as follows:

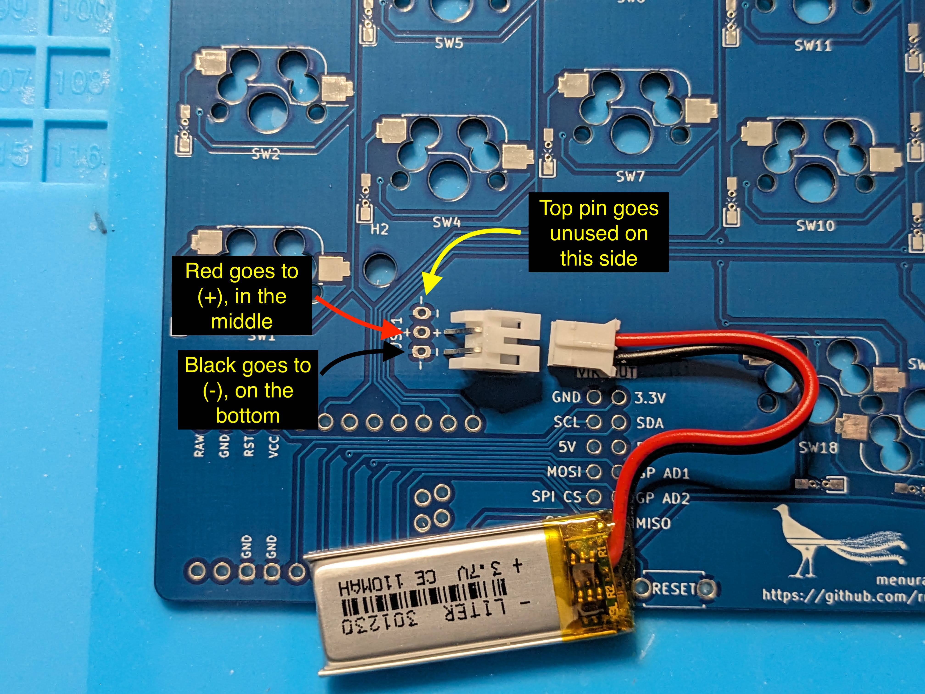
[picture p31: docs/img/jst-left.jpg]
jst-left

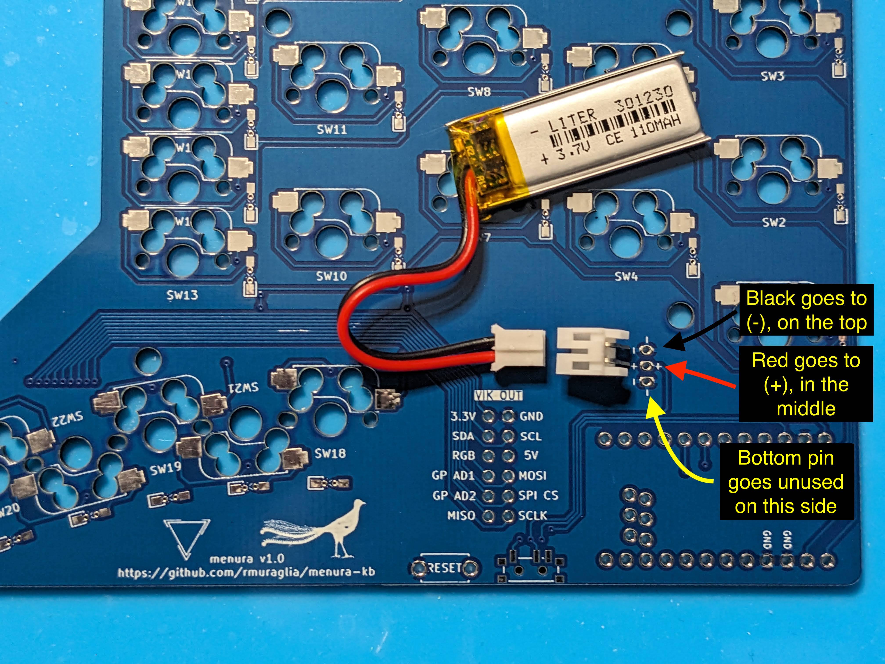
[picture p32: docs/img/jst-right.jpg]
jst-right


### MCU orientation

To verify the MCU orientation, use the labeled pins like GND, RST and VCC as reference points, and ensure that they will be aligned between the MCU and PCB.
Adhering to this simple constraint will guarantee that you install it correctly, rather than trying to remember or interpret "face up", "components down" or some other phrase.

I always like to use the consecutive ground pins as my reference point.
Cross reference with the [nice!nano pinout diagram](https://nicekeyboards.com/docs/nice-nano/pinout-schematic/) to make sure you're reading the pin labels on your MCU correctly:

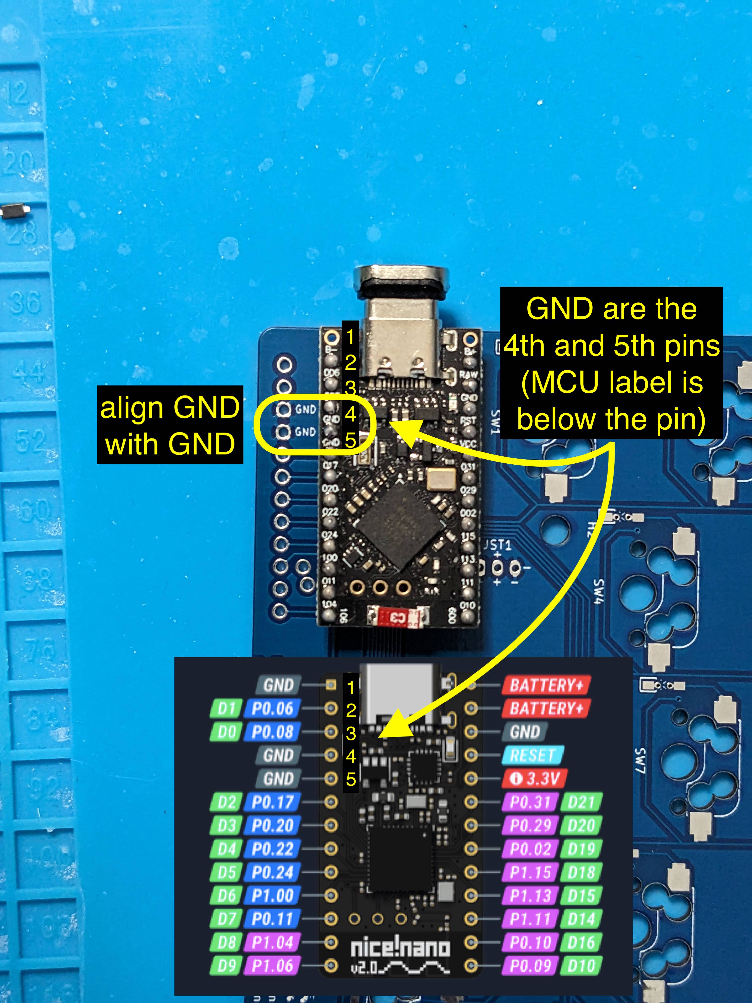
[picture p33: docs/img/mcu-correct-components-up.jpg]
mcu-correct-components-up

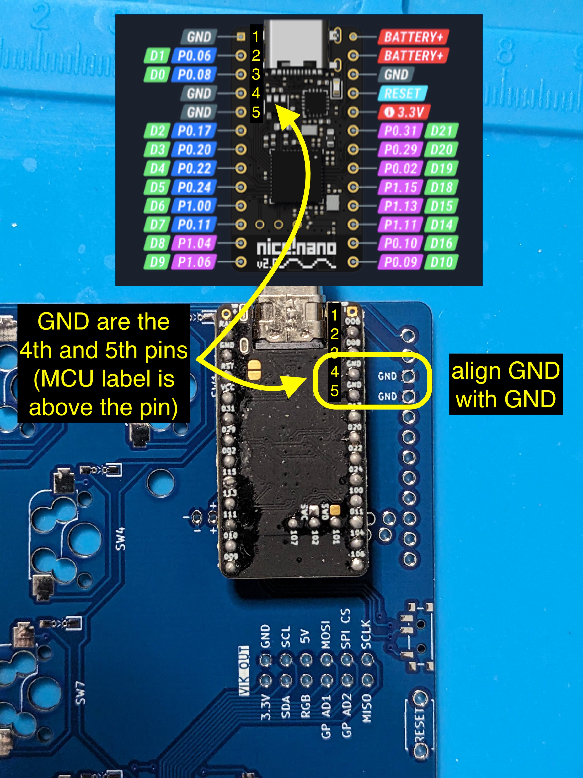
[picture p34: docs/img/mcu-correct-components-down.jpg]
mcu-correct-components-down

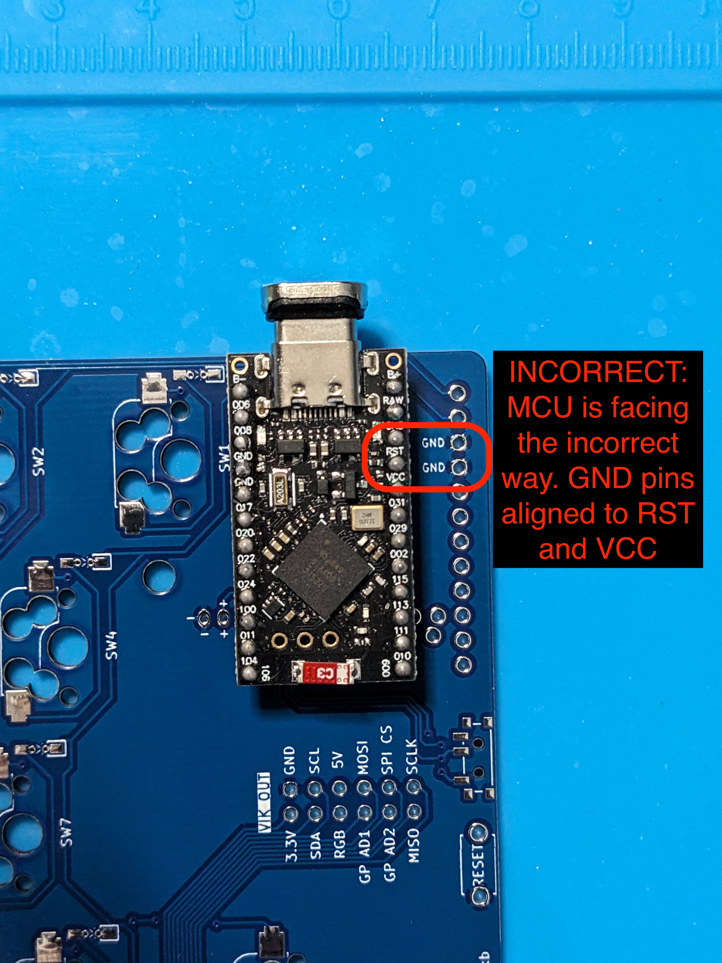
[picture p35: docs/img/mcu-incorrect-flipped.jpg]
mcu-incorrect-flipped

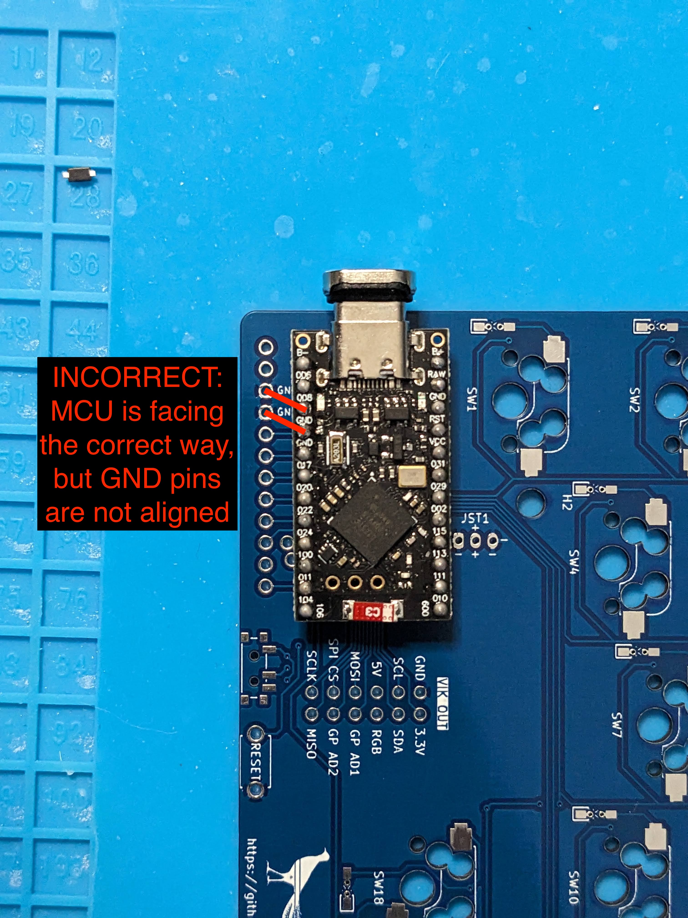
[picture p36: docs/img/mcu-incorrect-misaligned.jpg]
mcu-incorrect-misaligned


</details>

# Assembling the keyboard

## BOM

| Part | Quantity | Notes |
| --- | --- | --- |
| built menura pcb | 2 | |
| menura bottom plate | 2 | all layouts share one common bottom plate |
| menura top plate | 2 | choose the top plate corresponding to your layout (e.g. 3x5_3, 3x5_2 or 23332_2) |
| MX switches | 30-36 | |
| MX keycaps | 30-36 | |
| m2 screws | 16 | countersunk, 5mm works, other lengths are probably fine too |
| m2 spacers | 8 | 8mm |
| rubber feet | 8+ | e.g. 3M bumpons, SKUF rubber feet, adhesive neoprene etc |
| (optional) menura center wedge | 1 | choose a wedge corresponding to your desired distance and angle between halves when in unibody mode |
| (optional) magnets | up to 20 | 8x2mm round [example](https://www.amazon.com/gp/product/B09BB1VT4J/), tune magnet count to match desired strength of connection |

## Assembly

This is where the menura shines!
With one built PCB, you have the flexibility to choose between multiple layouts at assembly time, ranging from a 3x5+3 to a 23332+2 hummingbird.

Case files are published in the repo, under [`case/stl`](https://github.com/rmuraglia/menura-kb/tree/main/case/stl), with step files or fusion project files one directory above, if you prefer that format, or want to make tweaks to the case.  
Choose one (or more) `top_*` files, and experiment with different layouts!

> [!WARNING]
> Before installing the PCB into a case, it is highly recommended to [flash a test firmware](#studio) and verify that everything is working as expected

1. Insert a few (4-ish) switches into the top plate. I usually use the switches in the corners.
2. Insert the switch pins from that assembly into the PCB's hotswap sockets
3. Ensure that all the switches look well aligned
4. Insert the rest of the switches into the plate and PCB
5. From the bottom, insert the spacers through the PCB's mounting holes
6. From the top, screw in a set of screws to hold the spacers in place
7. Align the bottom plate with the spacers, and screw in the second set of screws
8. If inserting magnets, press fit them into the holes
    1. double check the magnet orientation before insertion
    2. the hole's tolerance may be slightly off -- you may need to either scrape the hole with a blade to make more room, or use a dot of glue to hold the magnet in place
9. Stick on a set of rubber feet
10. Install keycaps

# Flashing firmware

## Studio

The firmware included with the [releases](https://github.com/rmuraglia/menura-kb/releases) support [ZMK studio](https://zmk.dev/docs/features/studio) for easy UI-based keymap configuration without requiring building or flashing new firmware to your keyboard.
If you are more familiar with QMK, ZMK studio is analogous to Vial for QMK.

The stock keymap looks like this:

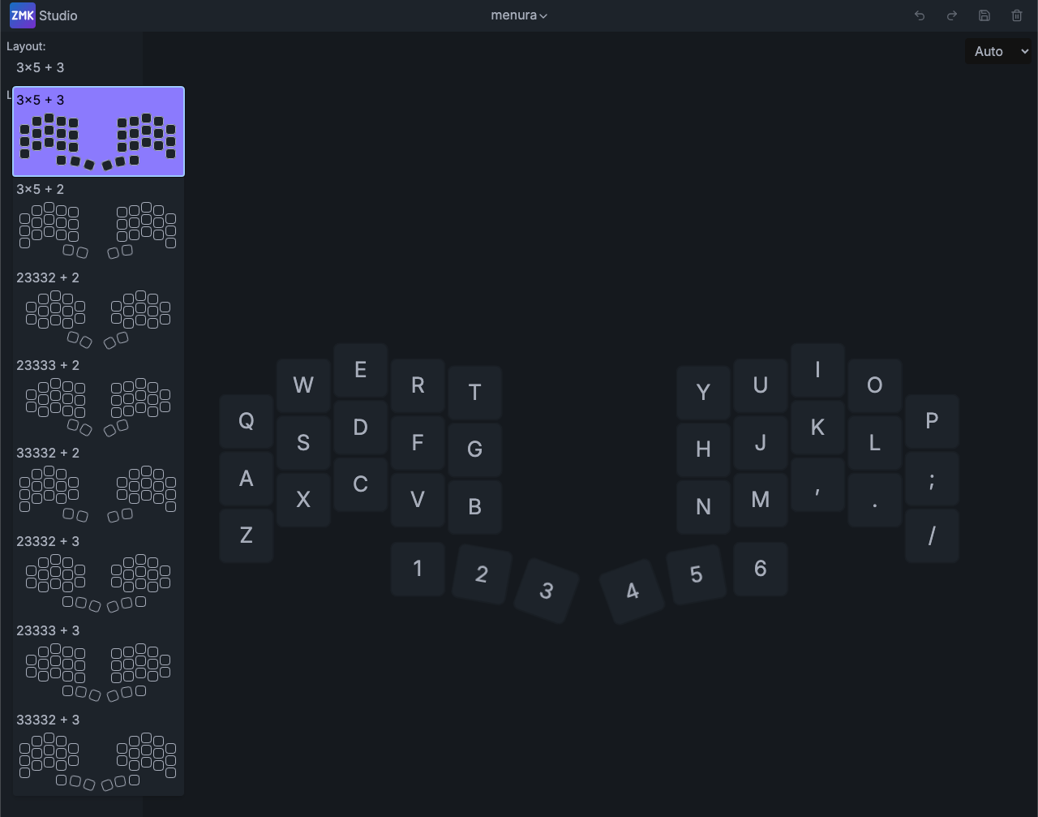
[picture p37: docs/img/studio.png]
studio


This keymap is only really intended for testing that all switch positions are functioning appropriately.  
When you are ready to customize your layout, the `&studio_unlock` binding is triggered by pressing four keys simultaneously:

- for layouts with 3 keys in the pinky columns, this will be the top two pinky keys on each side. Assuming the stock layout, this will be the Q, A, P and ; keys
- for layouts with 2 keys in the pinky columns, this will be all four pinky keys

Once you are in the studio UI, you can remap keys, add layers, and even change the layout.
The screenshot above shows the available layouts in the drop down menu.

Note that when you load up studio, the top pinky keys may appear blank or different -- this is because they are actually custom hold tap behaviors used for entering the bootloader if you want to flash custom firmware (see the ZMK config section below for more information).
Be cautious in remapping these keys if you plan on going that route down the line, and do not have easy access to your physical reset button.

## ZMK config

If you want to create your own ZMK config and define your keymap in code, the [menura shield definition](https://github.com/rmuraglia/zmk-keyboards-menura) is accessible as a [ZMK module](https://zmk.dev/docs/features/modules).  
This means you only need to add the menura module to your projects list in your `west.yml`, then the menura shield will be available to your builds.

For a tangible example, here's how my `zmk-config` uses the menura module:

- first I [add a new remote](https://github.com/rmuraglia/zmk-config/blob/8d228a5c4ef68459f12914036d7ad219430e42fd/config/west.yml#L15-L16) for the menura repo's github url base
- then I [add the menura project](https://github.com/rmuraglia/zmk-config/blob/8d228a5c4ef68459f12914036d7ad219430e42fd/config/west.yml#L35-L37). note that I use a non-main revision, but that's for testing something unrelated -- you should use the main branch
- then under [`zmk-config/config/`](https://github.com/rmuraglia/zmk-config/tree/8d228a5c4ef68459f12914036d7ad219430e42fd/config) I add my menura keymap and conf files
    - note that if you are using a layout other than the default 3x5+3, you may want to declare a [chosen node](https://github.com/rmuraglia/zmk-keyboards-menura/blob/main/boards/shields/menura/menura.dtsi#L146-L149) with the appropriate layout, like `&menura_23332_2_layout`.
- finally, I add the menura to my [github actions build list](https://github.com/rmuraglia/zmk-config/blob/8d228a5c4ef68459f12914036d7ad219430e42fd/build.yaml#L31-L34)

To enter the bootloader for flashing firmware, you can quickly double tap the reset button, but if that's inaccessible or inconvenient, the stock keymap from the previous section also provides a [hold-tap](https://zmk.dev/docs/keymaps/behaviors/hold-tap) for entering the bootloader on each half: simply press and hold the top pinky key (Q or P, conventionally) for 2 seconds.

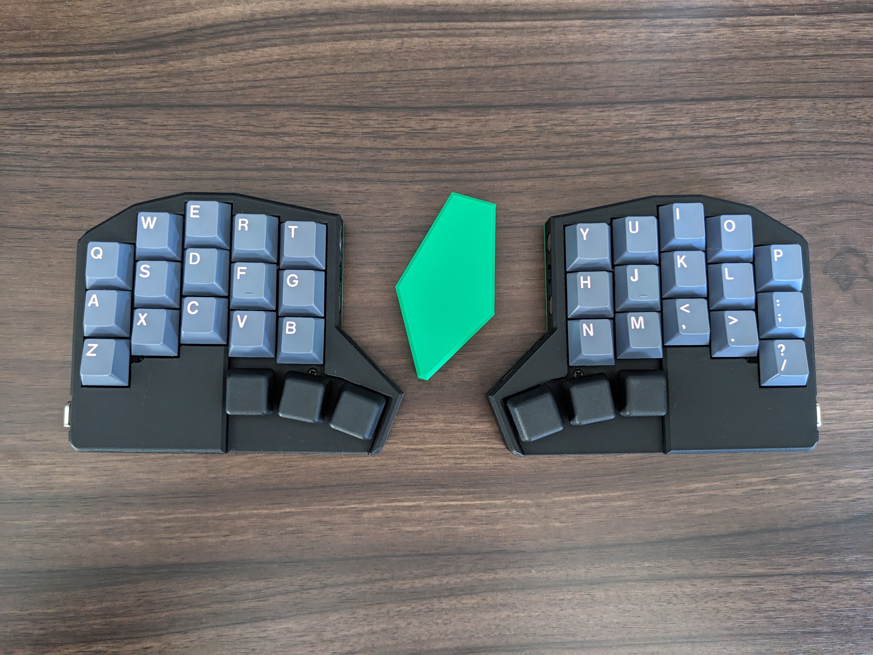
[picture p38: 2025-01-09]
docs/img/build-ffkb-split.jpg

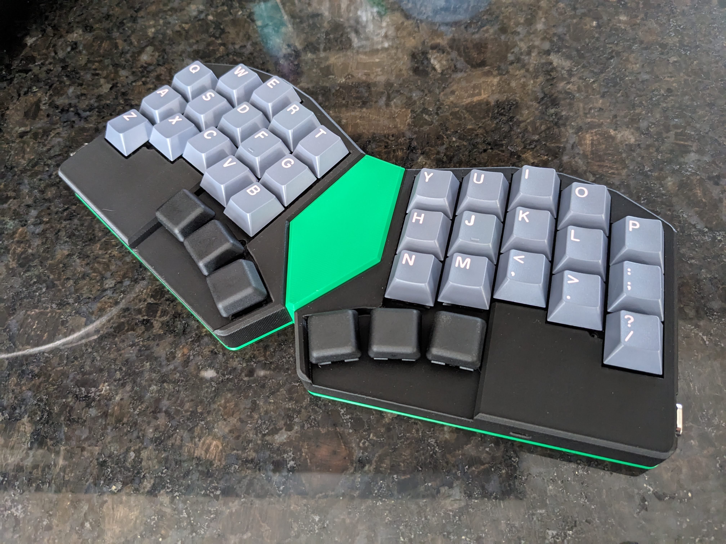
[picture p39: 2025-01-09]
docs/img/build-ffkb.jpg

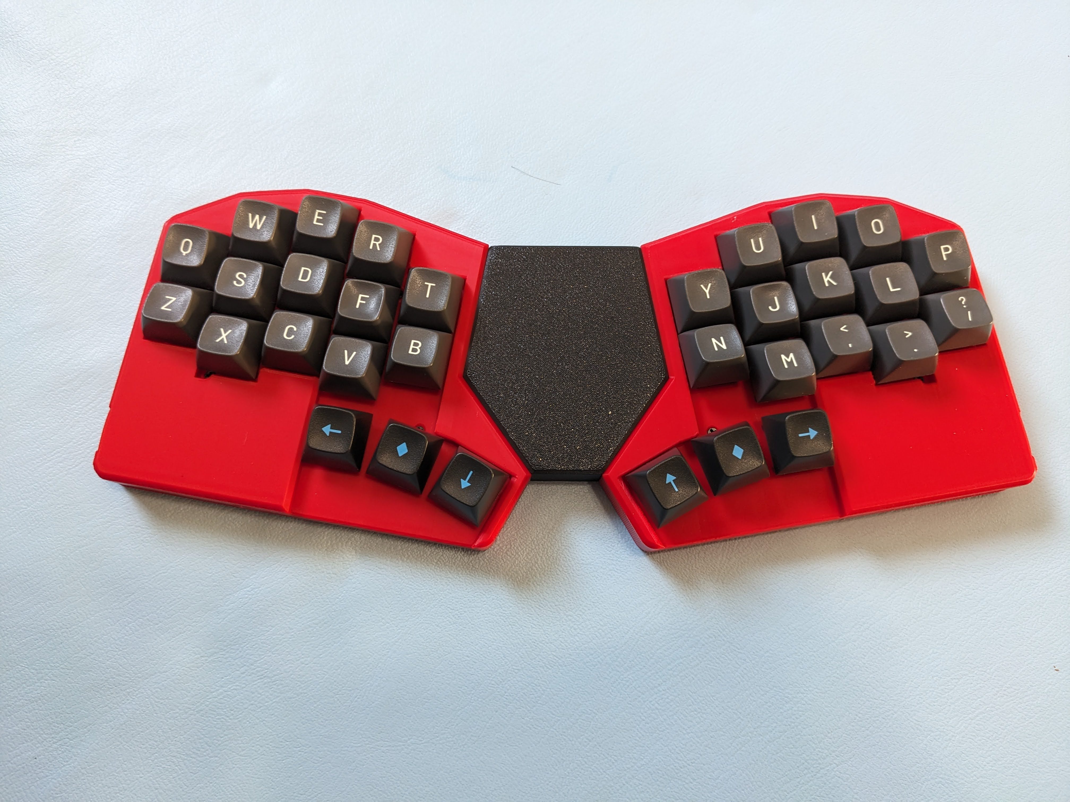
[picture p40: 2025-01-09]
docs/img/build-thummingbird.jpg

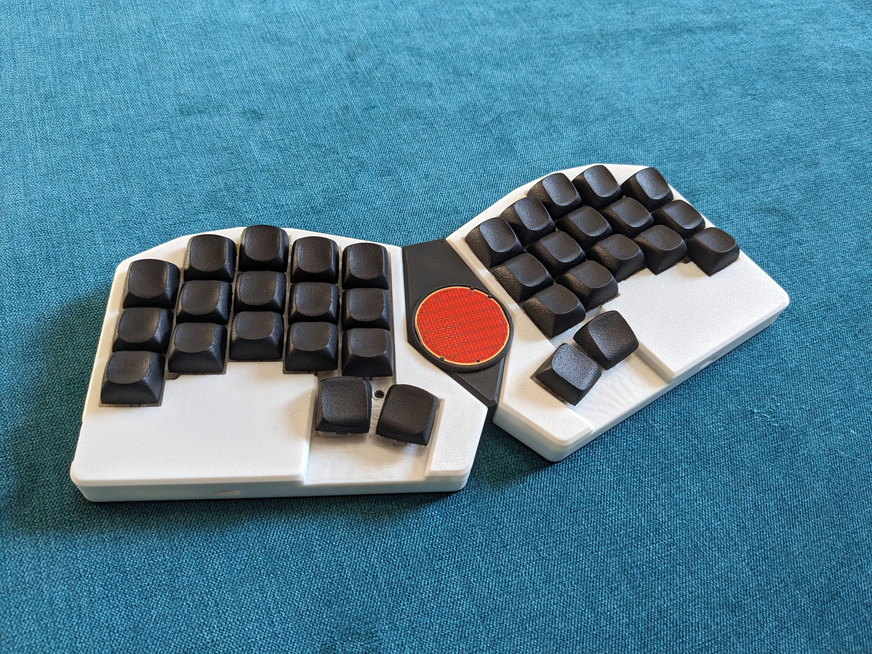
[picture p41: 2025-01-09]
docs/img/build-urchin-cirque.jpg

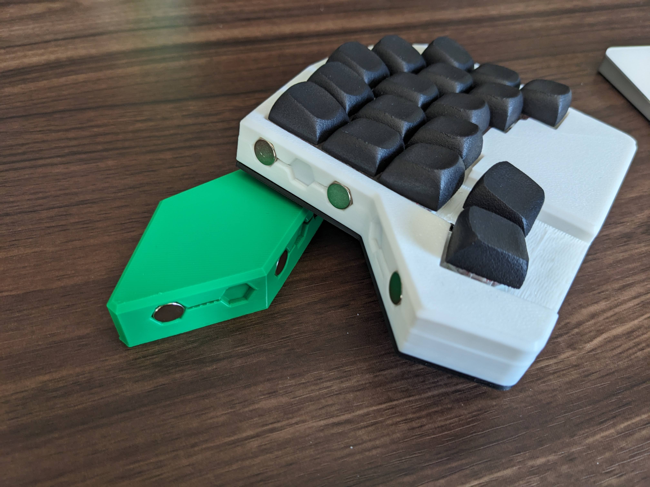
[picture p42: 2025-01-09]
docs/img/build-magnet-detail.jpg

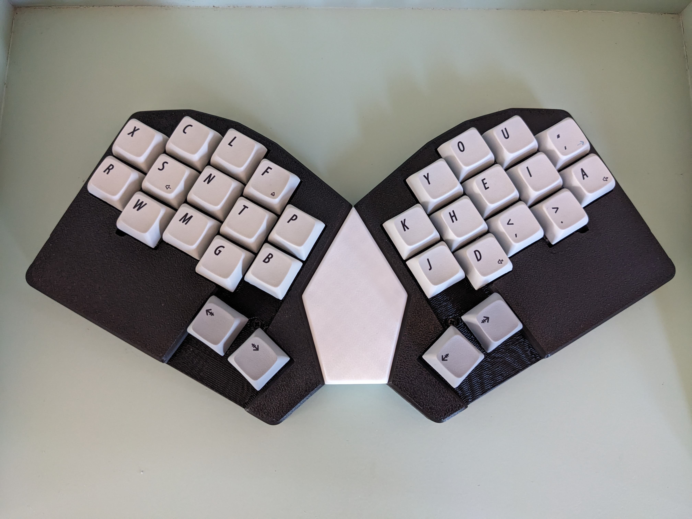
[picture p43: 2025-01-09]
docs/img/build-hummingbird.jpg

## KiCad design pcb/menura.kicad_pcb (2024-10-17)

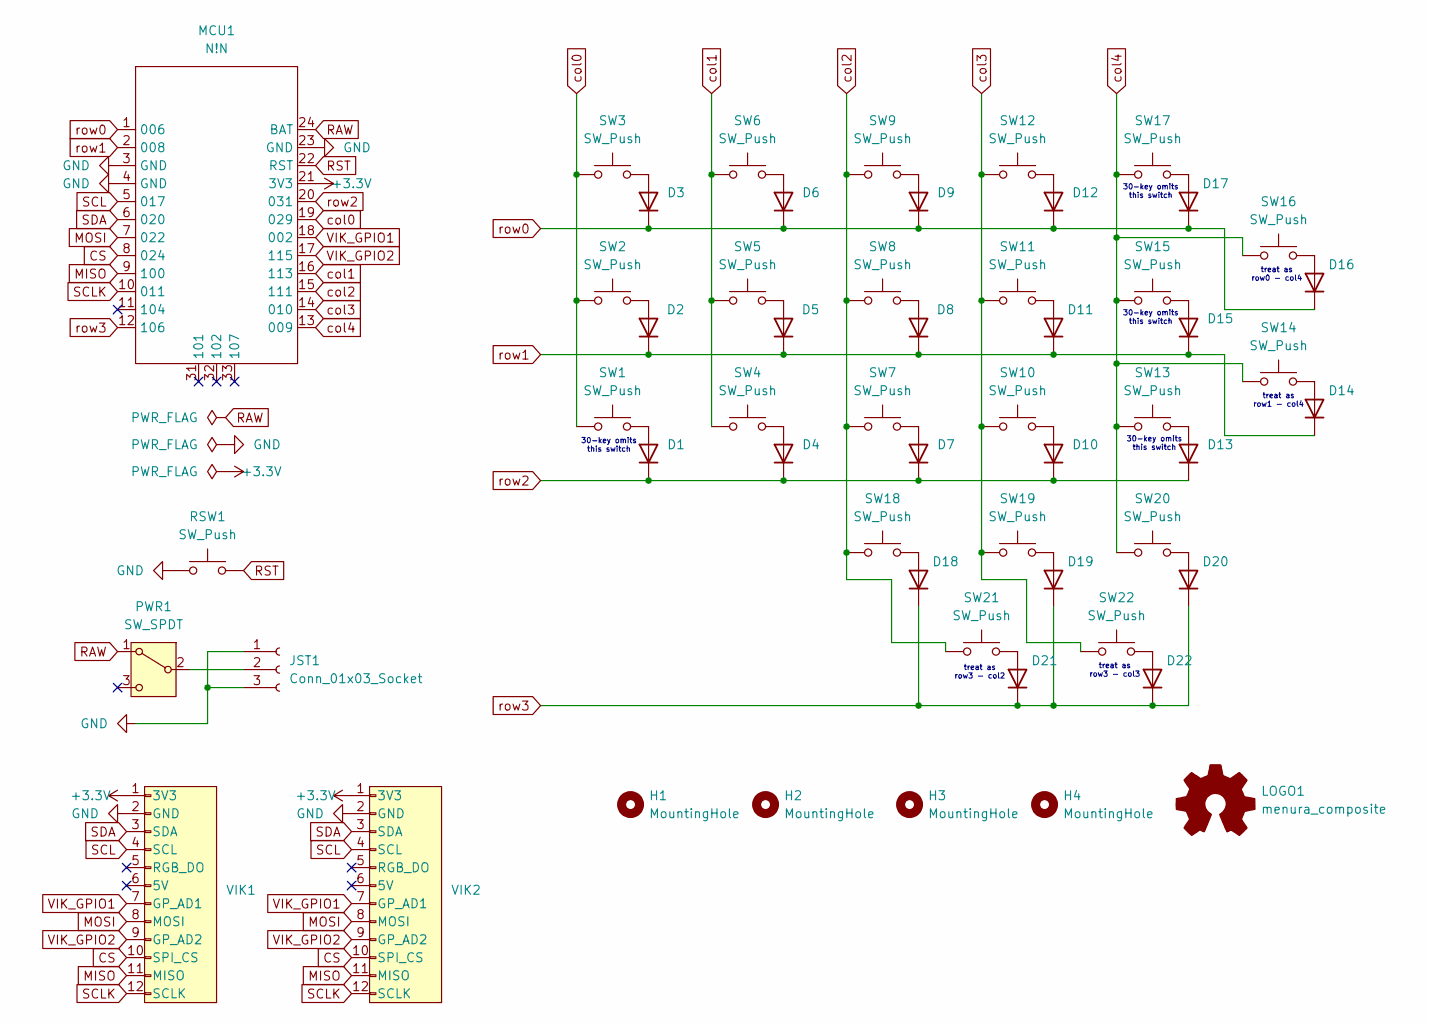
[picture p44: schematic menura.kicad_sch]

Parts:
D1, D2, D3, D4, D5, D6, D7, D8, D9, D10, D11, D12, D13, D14, D15, D16, D17, D18, D19, D20, D21, D22: 1N4148W; Diode_SMD-reversible-urchin
H1, H2, H3, H4: MountingHole; MountingHole_3.2mm_M3
JST1: Conn_01x03_Socket; Connector_JST-PH-3prong
LOGO1: menura_composite; Logo_menura_composite
MCU1: N!N; MCU_nice-nano
PWR1: SW_SPDT; Switch_power-reversible-kim
RSW1: SW_Push; Switch_reset-2pin
SW1, SW2, SW3, SW4, SW5, SW6, SW7, SW8, SW9, SW10, SW11, SW12, SW13, SW14, SW15, SW16, SW17, SW18, SW19, SW20, SW21, SW22: SW_Push; Switch_MX-hotswap-reversible
VIK1: Connector_vik-keyboard-horizontal
VIK2: Connector_vik-keyboard-throughhole

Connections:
+3.3V: MCU1.21 (3V3), VIK1.1 (3V3), VIK2.1 (3V3)
CS: MCU1.8 (024), VIK1.10 (SPI_CS), VIK2.10 (SPI_CS)
GND: JST1.1, JST1.3, MCU1.3 (GND), MCU1.4 (GND), MCU1.23 (GND), RSW1.1, VIK1.2 (GND), VIK2.2 (GND)
MISO: MCU1.9 (100), VIK1.11 (MISO), VIK2.11 (MISO)
MOSI: MCU1.7 (022), VIK1.8 (MOSI), VIK2.8 (MOSI)
unnamed: D1.2 (A), SW1.2
unnamed: D2.2 (A), SW2.2
unnamed: D3.2 (A), SW3.2
unnamed: D4.2 (A), SW4.2
unnamed: D5.2 (A), SW5.2
unnamed: D6.2 (A), SW6.2
unnamed: D7.2 (A), SW7.2
unnamed: D8.2 (A), SW8.2
unnamed: D9.2 (A), SW9.2
unnamed: D10.2 (A), SW10.2
unnamed: D11.2 (A), SW11.2
unnamed: D12.2 (A), SW12.2
unnamed: D13.2 (A), SW13.2
unnamed: D14.2 (A), SW14.2
unnamed: D15.2 (A), SW15.2
unnamed: D16.2 (A), SW16.2
unnamed: D17.2 (A), SW17.2
unnamed: D18.2 (A), SW18.2
unnamed: D19.2 (A), SW19.2
unnamed: D20.2 (A), SW20.2
unnamed: D21.2 (A), SW21.2
unnamed: D22.2 (A), SW22.2
unnamed: JST1.2, PWR1.2 (B)
RAW: MCU1.24 (BAT), PWR1.1 (A)
RST: MCU1.22 (RST), RSW1.2
SCL: MCU1.5 (017), VIK1.4 (SCL), VIK2.4 (SCL)
SCLK: MCU1.10 (011), VIK1.12 (SCLK), VIK2.12 (SCLK)
SDA: MCU1.6 (020), VIK1.3 (SDA), VIK2.3 (SDA)
VIK_GPIO1: MCU1.18 (002), VIK1.7 (GP_AD1), VIK2.7 (GP_AD1)
VIK_GPIO2: MCU1.17 (115), VIK1.9 (GP_AD2), VIK2.9 (GP_AD2)
col0: MCU1.19 (029), SW1.1, SW2.1, SW3.1
col1: MCU1.16 (113), SW4.1, SW5.1, SW6.1
col2: MCU1.15 (111), SW7.1, SW8.1, SW9.1, SW18.1, SW21.1
col3: MCU1.14 (010), SW10.1, SW11.1, SW12.1, SW19.1, SW22.1
col4: MCU1.13 (009), SW13.1, SW14.1, SW15.1, SW16.1, SW17.1, SW20.1
row0: D3.1 (K), D6.1 (K), D9.1 (K), D12.1 (K), D16.1 (K), D17.1 (K), MCU1.1 (006)
row1: D2.1 (K), D5.1 (K), D8.1 (K), D11.1 (K), D14.1 (K), D15.1 (K), MCU1.2 (008)
row2: D1.1 (K), D4.1 (K), D7.1 (K), D10.1 (K), D13.1 (K), MCU1.20 (031)
row3: D18.1 (K), D19.1 (K), D20.1 (K), D21.1 (K), D22.1 (K), MCU1.12 (106)

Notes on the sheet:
30-key omits this switch
treat as row3 - col3
treat as row3 - col2
treat as row1 - col4
treat as row0 - col4

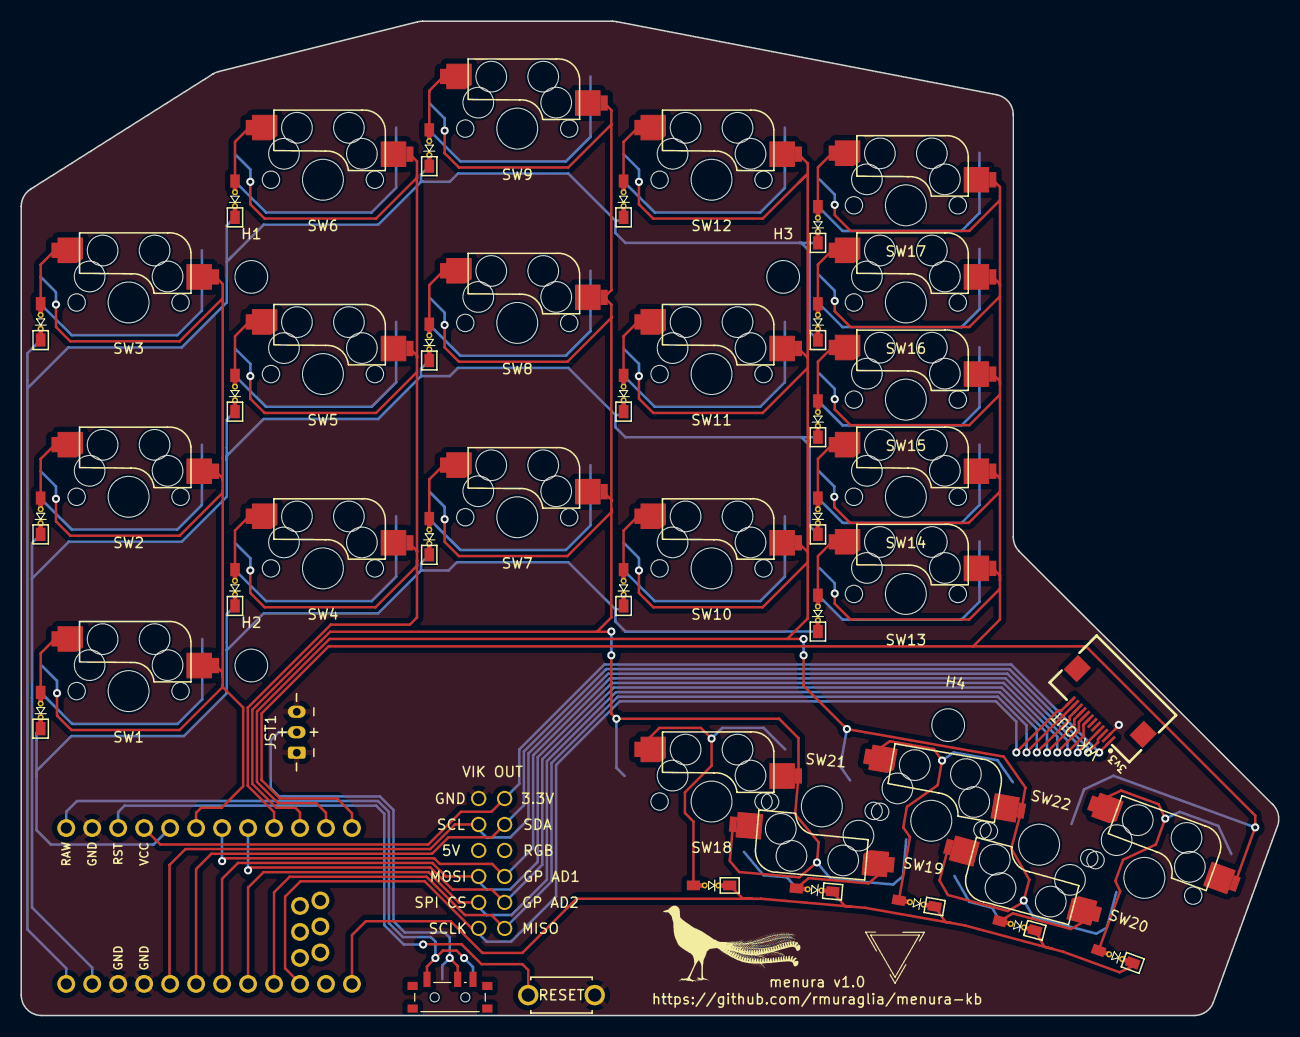
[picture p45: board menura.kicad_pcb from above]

Board: 2 copper layers, 123.0 x 97.2 mm, 55 parts (0 on the bottom side), 44 nets.

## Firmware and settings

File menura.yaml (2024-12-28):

units:
  # for the key matrix
  # mx spacing
  kx: u
  ky: u
  edge_padding: 1
  preview_key_adj: 0.5  # how much to shrink the keys in the preview, so boxes aren't overlapping

  # stagger and splay
  ring_stagger: ky/2 + 2.5
  middle_stagger: 5
  index_stagger: -5
  inner_stagger: -2.5
  thumb_splay: -5
  thumb_spread: 0.525kx
  thumb_drop_offset: -1.2ky

  # for the case
  sw_hole: 14  # size of hole for switch in plate
  keycap_padding: 0.5  # extra room to account for keycap
  inner_wall_offset: 1  # manufacturing tolerance around pcb outline
  outer_wall_offset: 3  # main case wall thickness
  shadow_inner_offset: 1.2  # offset from inner wall for shadow line inner piece
  shadow_outer_offset: outer_wall_offset - shadow_inner_offset  # offset for shadow line outer piece

  # for other components
  # nb: mcu footprint has the port pointing to the left
  mcu_x: 33
  mcu_y: 18
  mcu_padding: 2.11  # extra buffer between mcu to make bottom edge cut straight with thumbs
  mcu_adj: 7  # adjustment to align mcu (but not the port) and switch
  diode_adj_x: -8.6  # diode adjustment in main switch matrix
  diode_adj_y: -1.9
  diode_adj_thumb: -8.2  # diode adjustment in thumb cluster
  m3: 3.2  # m3 hole diameter (for an m2 standoff)
  m2cs: 4.4  # m2 countersunk hole clearance diameter
  # MSK-12C02 type power switch
  pwr_x: 5.85
  pwr_y: 8.8
  pwr_adj: 1.12 # align edge cut to pads (not physical toggle switch)
  pwr_mcu_x_offset: 5
  pwr_mcu_y_offset: -0.5mcu_y - mcu_padding + 0.5pwr_x - pwr_adj
  # generic through hole 2 pin 3x6x4.3mm button/switch e.g. MJTP1243
  rst_x: 9
  rst_y: 3.5
  rst_pwr_x_offset: 2
  rst_pwr_y_offset: -2.5 + mcu_padding + 0.2
  jst_x: 8.9
  jst_y: 8.6
  jst_x_adj: 0.1
  jst_y_adj: 2.2
  vik_x: 11
  vik_y: 9.1
  vik_adj_x: 4.5
  vik_adj_y: 3 - vik_adj_x
  vik_tht_x: 17
  vik_tht_y: 16
  vik_tht_adj_x: 2.5
  vik_tht_adj_y: 15
  hole_x_adj: 7
  logo_x: 33
  logo_y: 10.5
  logo_rst_x_offset: 25

points:
  zones:
    matrix:
      key:
        padding: 0.5ky
        spread: kx
        bind: [0, 0, 0, 0]
      anchor:
        shift: [100, -100]
      rows:
        bottom:
        bird_bottom:
        home:
        bird_top:
        top:
      columns:
        pinky:
          rows.bottom.tags: [pinky_3x5]
          rows.bird_bottom.skip: true
          rows.home.tags: [matrix_common]
          rows.bird_top.skip: true
          rows.top.tags: [matrix_common]
        ring:
          key:
            stagger: ring_stagger
            tags: [matrix_common]
          rows.bird_bottom.skip: true
          rows.bird_top.skip: true
        middle:
          key:
            stagger: middle_stagger
            tags: [matrix_common]
          rows.bird_bottom.skip: true
          rows.bird_top.skip: true
        index:
          key:
            stagger: index_stagger
            tags: [matrix_common]
          rows.bird_bottom.skip: true
          rows.bird_top.skip: true
        inner:
          key:
            stagger: inner_stagger
          rows.bottom.tags: [inner_3x5]
          rows.bottom.bind: [0, 0, 4, 0]
          rows.home.tags: [inner_3x5]
          rows.top.tags: [inner_3x5]
          rows.bird_bottom.tags: [inner_bird]
          rows.bird_bottom.bind: [0, 0, 14, 0]
          rows.bird_top.tags: [inner_bird]
    thumbs:
      key:
        padding: ky
        spread: thumb_spread
        bind: [0, 0, 0, 0]
        splay: thumb_splay
        origin: [-0.5thumb_spread, -0.5ky]
      anchor:
        ref: matrix_index_bottom
        shift: [0, thumb_drop_offset]
      rows:
        cluster:
      columns:
        tucky:
          key:
            splay: 0
            tags: [3thumb]
            bind: [4, 2, 0, 0]
        midtucky:
          key.tags: [2thumb]
          key.bind: [4, 2, 0, 0]
        home:
          key.tags: [3thumb]
          key.bind: [0, 2, 0, 2]
        midreachy:
          key.tags: [2thumb]
          key.bind: [0, 0, 0, 2]
        reachy:
          key.tags: [3thumb]
          key.bind: [0, 0, 0, 2]
    mcu:
      key:
        width: mcu_x
        height: mcu_y
      anchor:
        ref: matrix_pinky_bottom
        shift: [mcu_adj, -0.5ky - 0.5mcu_y - mcu_padding]
    jst:
      key:
        width: jst_x
        height: jst_y
        rotate: 90
      anchor:
        ref: matrix_ring_bottom
        shift: [-jst_x_adj, -0.5ky - 0.5jst_y - jst_y_adj]
    pwr:
      key:
        width: pwr_x
        height: pwr_y
        rotate: 270
      anchor:
        ref: mcu
        shift: [0.5mcu_x + 0.5pwr_x + pwr_mcu_x_offset, pwr_mcu_y_offset]
    rst:
      key:
        width: rst_x
        height: rst_y
      anchor:
        ref: pwr
        shift: [rst_pwr_y_offset, 0.5pwr_y + 0.5rst_x + rst_pwr_x_offset]
        rotate: 90
    vik:
      key:
        width: vik_x
        height: vik_y
      anchor:
        ref: matrix_inner_bottom
        shift: [0.5kx + 0.5vik_x + vik_adj_x, -0.5ky + vik_adj_y]
        rotate: 135
    vik_tht:
      key:
        width: vik_tht_x
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

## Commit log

2024-08-31 basic switch footprint layout
2024-08-31 add diodes to pcb
2024-08-31 pcb todos
2024-10-02 component placement, schematic
    [menura.kicad_pcb, menura.kicad_sch]
2024-10-03 fix diode ordering
    [menura.kicad_pcb, menura.kicad_sch]
2024-10-03 fix: spi pins should be high freq
    [menura.kicad_sch]
2024-10-03 update footprints: centering, pad assignments
    [menura.kicad_pcb]
2024-10-04 iterate on power switch and jst placement
    [menura.kicad_pcb]
2024-10-04 iterate on vik placement
    [menura.kicad_pcb]
2024-10-04 more vik footprints
2024-10-04 add vik throughole breakout
    [menura.kicad_pcb, menura.kicad_sch]
2024-10-04 tweak reset button placement
    [menura.kicad_pcb]
2024-10-05 yaml comments
    [menura.kicad_pcb]
2024-10-06 edge cut wip
    [menura.kicad_pcb]
2024-10-06 adjust vik position and rotation
    [menura.kicad_pcb]
2024-10-07 shuffle few components around
    [menura.kicad_pcb]
2024-10-07 tweak urchin diode footprint, add tenting puck footprints
    [menura.kicad_pcb]
2024-10-08 logo silkscreens
    [menura.kicad_pcb, menura.kicad_sch]
2024-10-08 add mounting holes
    [menura.kicad_pcb]
2024-10-09 one more pth
    [menura.kicad_pcb, menura.kicad_sch]
2024-10-09 remove plated holes on inner edge
    [menura.kicad_pcb, menura.kicad_sch]
2024-10-09 reorder a few pins
    [menura.kicad_pcb, menura.kicad_sch]
2024-10-09 reference boards in readme
2024-10-10 bird silhouette logo
    [menura.kicad_pcb, menura.kicad_sch]
2024-10-10 satisfy erc
    [menura.kicad_sch]
2024-10-10 regen pcb before routing
    [menura.kicad_pcb]
2024-10-10 scoot the bird
    [menura.kicad_pcb]
2024-10-15 routing partially done
    [menura.kicad_pcb, raw.kicad_pcb]
2024-10-17 route thumb area
    [menura.kicad_pcb, raw.kicad_pcb]
2024-11-23 3x5_3 first case attempt
    [bottom.f3d, bottom.step, bottom_left.stl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]
2024-11-24 15 degree, 2mm wedge
    [wedge_15deg_2mm.f3d, wedge_15deg_2mm.step, wedge_15deg_2mm.stl]
2024-11-24 update sketches
    [case_plate_23332_2.dxf, case_plate_3x5_3.dxf]
2024-11-24 update fusion
    [plate_3x5_3.f3d]
2024-11-24 update step
    [plate_3x5_3.step]
2024-11-24 update stls
    [top_3x5_3_left.stl, top_3x5_3_right.stl]
2024-11-24 more vertical allowance for usb (right side is lower)
    [plate_3x5_3.f3d, plate_3x5_3.step, top_3x5_3_left.stl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]
2024-11-25 tiny gap in dxf
    [case_plate_23332_2.dxf]
2024-12-14 add more case dxfs
    [case_plate_23332_3.dxf, case_plate_3x5_2.dxf]
2024-12-21 build guide and case docs
2024-12-21 rename plate -> top
    [top_3x5_3.f3d, top_3x5_3.step]
2024-12-21 add hummingbird case files
    [top_23332_2.f3d, top_23332_2.step]
2024-12-21 add hummingbird case stls
    [top_23332_2_left.stl, top_23332_2_right.stl]
2024-12-22 revise 3x5_3 case
    [top_3x5_3.f3d, top_3x5_3.step, top_3x5_3_left.stl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]
2024-12-22 revise wedge
    [wedge_15deg_2mm.f3d, wedge_15deg_2mm.step, wedge_15deg_2mm.stl]
2024-12-22 change wedge naming convention
    [wedge_15deg_18mm.f3d, wedge_15deg_18mm.step, wedge_15deg_18mm.stl]
2024-12-22 sharp angle wedge
    [wedge_30deg_0mm.f3d, wedge_30deg_0mm.step, wedge_30deg_0mm.stl]
2024-12-22 relaxed angle wedge
    [wedge_10deg_34mm.f3d, wedge_10deg_34mm.step, wedge_10deg_34mm.stl]
2024-12-22 relaxed, wide wedge
    [wedge_10deg_50mm.f3d, wedge_10deg_50mm.step, wedge_10deg_50mm.stl]
2024-12-22 case top variants with no reset button hole
    [top_23332_2_left_no-rst.stl, top_23332_2_right_no-rst.stl, top_3x5_3_left_no-rst.stl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]
2024-12-23 23332_3 cases
    [top_23332_3.f3d, top_23332_3.step, top_23332_3_left.stl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]
2024-12-23 close face in sketch
    [case_plate_3x5_2.dxf]
2024-12-23 add 3x5_2 cases
    [top_3x5_2.f3d, top_3x5_2.step, top_3x5_2_left.stl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]
2024-12-25 cirque wedge
    [cirque.dxf, cutout-pwr.dxf, cutout-usb.dxf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]
2024-12-28 33332_3 case
    [case_plate_33332_3.dxf, top_33332_3.f3d, top_33332_3.step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]
2025-01-09 fix typo in battery images
2025-01-09 add sample build pictures
2025-01-10 note on controller soldering
